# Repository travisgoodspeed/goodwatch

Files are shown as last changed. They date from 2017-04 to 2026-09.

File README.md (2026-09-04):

Howdy y'all,

This is a side project of mine to build a replacement circuit board
for the Casio 3208 module, used in the Casio CA-53W and CA-506
calculator watches.  It is not compatible with the 3228 module used in
the Databank watches, which have four external buttons instead of two.
As a side project, it has no warranty whatsoever and you shouldn't use
it for anything.

In the rare case that you find this project to be useful, you owe me a
pint of good, hoppy pale ale.  All license to use this project is
revoked if you try to pass off a pilsner instead.

In addition to the source code, there is handy documentation in the
[wiki](https://github.com/travisgoodspeed/goodwatch/wiki) and a
general interest website at [goodwatch.org](http://goodwatch.org/).
The wiki's
[DeveloperGuide](https://github.com/travisgoodspeed/goodwatch/wiki/DeveloperGuide)
page might be particularly handy.

73 from Knoxville,

--Travis

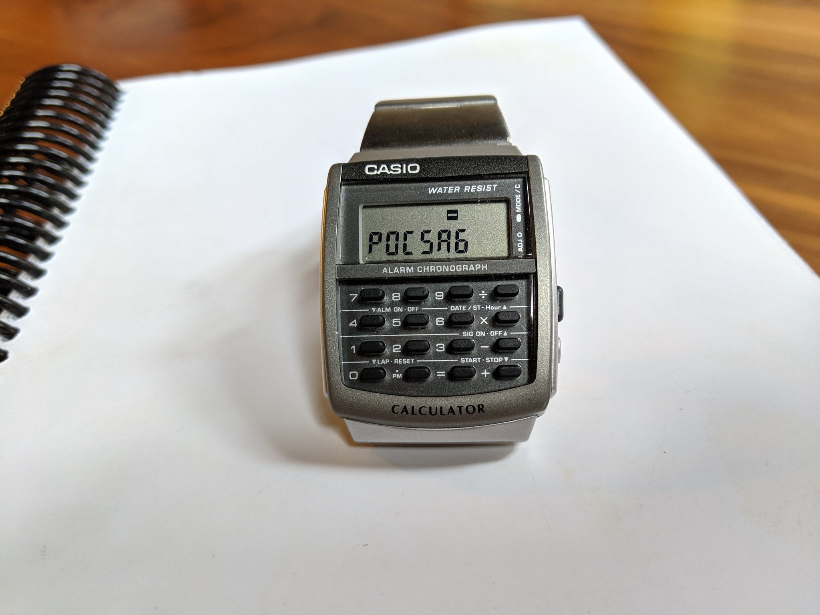
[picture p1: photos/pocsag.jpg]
POCSAG Goodwatch Photo


## Software Status

Our firmware is freely available in this repository, compiling with
the MSP430 GCC compiler packages from Texas Instruments.  It consists
of a
[Clock](https://github.com/travisgoodspeed/goodwatch/wiki/ClockApplet),
a Stopwatch, an RPN Calculator, and a [Hex Memory
Viewer](https://github.com/travisgoodspeed/goodwatch/wiki/HexApplet)
with Disassembler, all written in C.  It compiles in Debian with all
of the MSP430 packages installed.

On watches with a radio, we have
[Morse](https://github.com/travisgoodspeed/goodwatch/wiki/MorseApplet)
and GFSK transmitters, as well as an [OOK
transmitter](https://github.com/travisgoodspeed/goodwatch/wiki/OOK_Example)
that will command cheap remote-controlled relays.  It has a [frequency
counter](https://github.com/travisgoodspeed/goodwatch/wiki/CounterApplet).
The radio is accessible from a host computer over the UART for
building base stations and repeaters, or for rapidly prototyping radio
applications in Python.  P25 and DMR support might come soon.

Additionally, we've written our own client for the CC430's BootStrap
Loader (BSL).  You might find it handy for other projects involving
that chip, or other MSP430F5 and MSP430F6 chips without USB.  You will
need to be a member of the `dialout` group to flash the firmware.

## Hardware Status

Our replacement board is based around the CC430F6147, which combines
an MSP430 microcontroller with an LCD controller and a sub-GHz radio.
Thanks to pin compatibility, our fancy linker scripts produce a
firmware image that works just as well on the older CC430F6137
chip.

The
[GoodWatch30](https://github.com/travisgoodspeed/goodwatch/wiki/GoodWatch30)
is our current hardware revision, with filters that run from 300 MHz
to either 500MHz or 915MHz.  The GoodWatch20 family had narrower
filters at 433MHz, but is still supported.

See `BOM.txt` in the hardware directories for a parts list, and the
wiki for an assembly guide.

## Related Projects

[Pluto](https://github.com/carrotIndustries/pluto) is a replacement
PCB for the Casio F-91W that is also based on an MSP430.  We happily
use that project's [energy
monitor](https://github.com/carrotIndustries/energytrace-util)
utility for measuring our power budget.

[Elektronika-1](https://github.com/BenjaminSoelberg/elektronika-1) is
Benjamin Sølberg's replacement board for the Soviet Электроника-1
watch, based on an MSP430FR2433.

[Sensor Watch](https://github.com/joeycastillo/Sensor-Watch/) is Joey
Castillo's ATSAML22 replacement board for the Casio F-91W.  He adds a
backlight, and a 9-pin flex PCB allows you to add a custom sensor to
the watch, rather than have one built into the board.

[Outatime Pro](https://github.com/evyd13/outatime-pro) from Evelien
Dekkers is a replacement board that matches the same Casio
3208 casings as the GoodWatch, but is based on the Sensor Watch Pro.
It adds backlight, a 9-pin FPC connector for custom sensors or boards,
and a PAM8904 for a louder buzzer without the large inductor.

The [CharlieWatch](https://github.com/osresearch/charliewatch) from
Trammell Hudson is a nice little fork of the GoodWatch that uses a
charlieplexed array of LEDs instead of a Casio watchcase.

[iceSIO](https://github.com/icelord75/icesio) matches the same Casio
3208 casings as the GoodWatch, but uses a PIC16 platform with
accelerometer, compass and environmental sensors.

[FaradayRF](https://faradayrf.com/) is a CC430 radio board intended
for amateur use, with a 500mW amplifier and GPS receiver.  Their radio
chain is far more carefully designed than ours, but in time, we hope
that the two projects will communicate with each other.

[openchronos-ng-elf](https://github.com/BenjaminSoelberg/openchronos-ng-elf)
seems to be the most recently maintained firmware for TI's OpenChronos
devkit, which uses the CC430F6137.  See Adam Laurie's
[ChronIC](http://adamsblog.rfidiot.org/2013/03/you-can-ring-my-bell-adventures-in-sub.html)
project for an early example of sniffing OOK traffic and replaying it
from a watch.

[F91 Kepler](https://gitlab.com/_Pegor/kepler_fw) is an OLED and BTLE
replacement for the Casio F91W module.  It uses a CC2640 and has some
rather good documentation.

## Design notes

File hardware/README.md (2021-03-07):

These directories contain different hardware revisions of the
GoodWatch.  When a revision is manufactured, its files are copied to a
new directory and the old may only be updated for documentation
reasons.

The GoodWatch 22 and earlier were designed in Kicad 4, and might be
awkward to open in newer revisions.  The GoodWatch30 is designed in
Kicad 5.

## GoodWatch 30

This is our current design, featuring a new balun and more generous
filters.  Email Travis for some free PCBs if you'd like to build one.

## GoodWatch 20, 21, 22

These designs are outdated, but still supported by software.  They
have a narrower filter at 433MHz than the GoodWatch30, and sharp corners which must be clipped before assembly.

## GoodWatch 10

This was the first GoodWatch, which lacked a radio and had minor
mechanical misalignments.  You probably don't want this one anymore.

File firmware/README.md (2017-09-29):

Howdy y'all,

The GoodWatch firmware is in this directory.  You will find user-level
applications in the `apps/` subdirectory, while `*.c` in the root
directory contain low-level drivers.

To add your own application, for one of the smaller examples, such as
`stopwatch.c`.  Your app must provide functions for `_init()` (to run
at startup), `_draw()` (to run every quarter-second for rendering),
and `_exit()` which should just return 0 unless you need to intercept
the Mode button, in which case it may return 1 to delay the exit.  Add
these three functions to a line of the `apps[]` structure in
`applist.h`.

In general, we try not to over-abstract the hardware because we don't
intend the design to be portable away from the CC430.  Include
`<msp430.h>` if you need to access the CC430's IO registers or
`"api.h"` for all the standard functions of the GoodWatch firmware.

Cheers,

--Travis

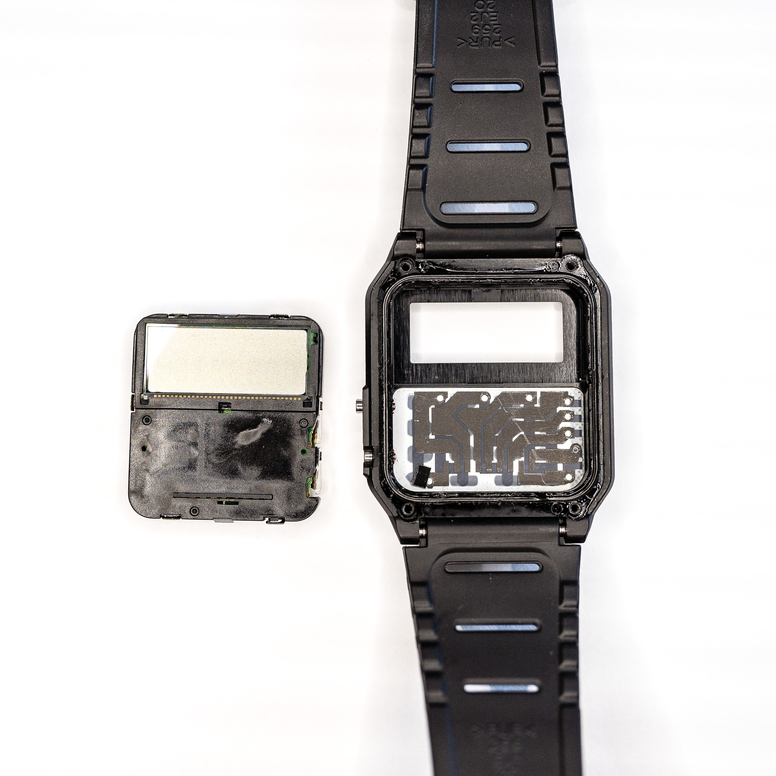
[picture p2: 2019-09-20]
photos/core_module.jpg

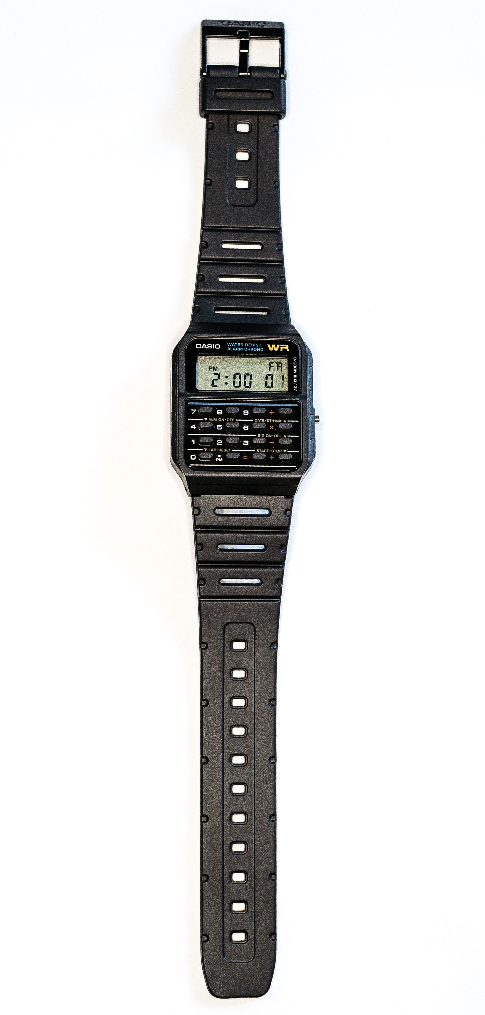
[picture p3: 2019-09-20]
photos/Casio_CA-53W.jpg

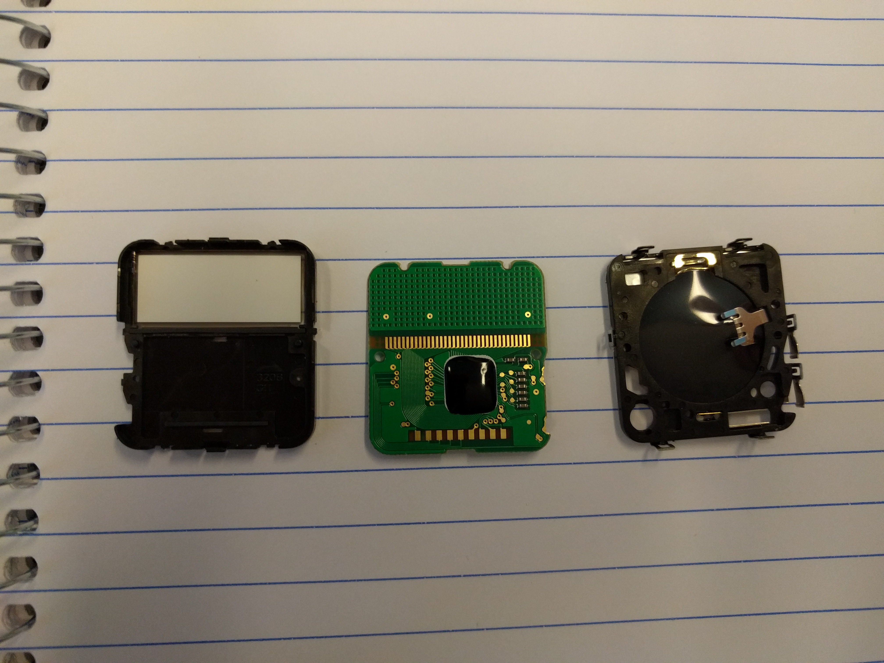
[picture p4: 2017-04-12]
photos/top.jpg

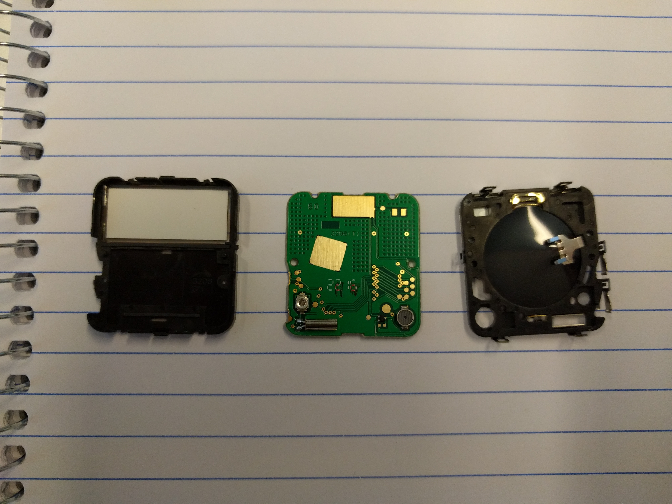
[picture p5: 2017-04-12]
photos/bottom1.jpg

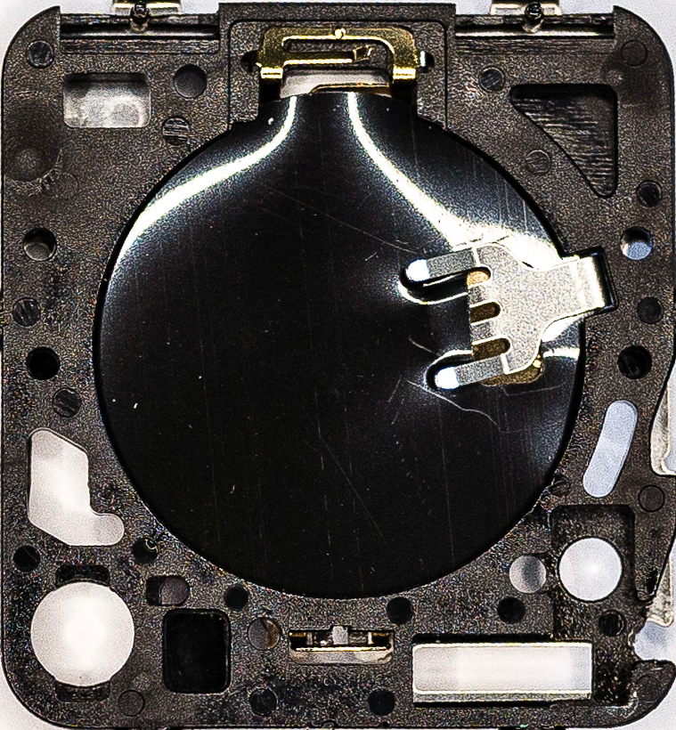
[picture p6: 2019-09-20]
photos/Battery_top.png

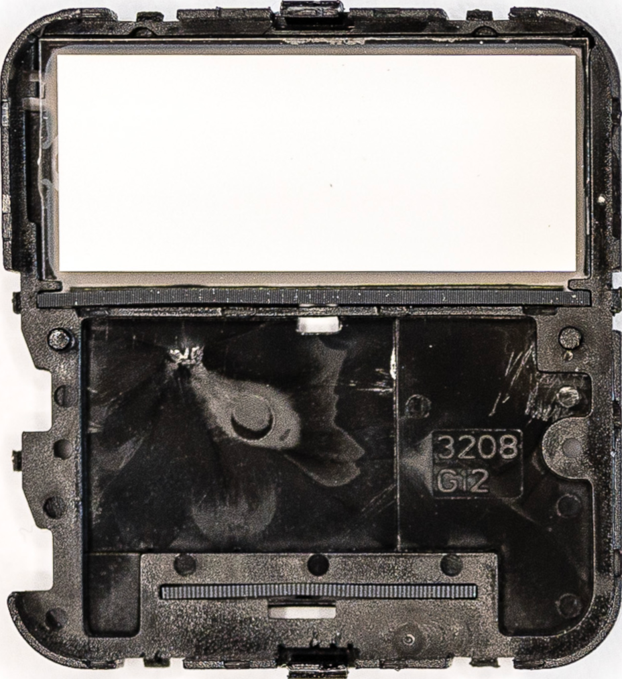
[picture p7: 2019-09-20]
photos/LCD_bot.png

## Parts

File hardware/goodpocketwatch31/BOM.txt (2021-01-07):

Howdy y'all,

This is a textfile BOM for the GoodPocketWatch31. Some substitutions
will be handy, allowing for supplier availability. In general, we use
the same parts as the GoodWatch31, except that the keypad now comes
from tactile switches, and an FTDI chip is available for convenient
USB reprogramming.  You'll probably use a GPW to develop firmware,
while wearing a GoodWatch.

Base parts, required for all watches.

        MfgrPartNo              Digikey             Pkg      Qty   Cmt
U1      CC430F6147IRGCR         296-39985-1-ND      VQFN64   1     CPU
R1      RMCF0402JT75K0          RMCF0402JT75K0CT-ND 0402     1     75K
C1      CL10A476MR8NZNE         1276-6528-1-ND      0603     1     47uF
C2,C3   GRM152C80J104KE19D      490-9997-1-ND       0402     2     0.1uF (<0.3mm thickness)
C4      GRJ155R60J106ME11D      490-13211-1-ND      0402     1     10uF
C5      CL05A474KP5NNNC         1276-1173-1-ND      0402     1     0.47uF
Y1      ABS07-120-32.768KHZ-T   535-11937-1-ND      SMDXTAL  1     32.768kHz6pF

Keypad parts.

B1-17   TL6700AF160QG           EG4385TR-ND                 17     SPST Tactile Switch
BPGM    TL6700NF260QG           EG4386TR-ND                  1     SPST Tactile Switch

Misc Parts

BZ1     PT-1203-3               433-1201-2-ND       THP      1
BT1,2   BE-AAAA-PC-ND           BE-AAAA-PC	    THP	     2     AAAA Battery Holder

Radio parts, only required for the optional SubGHz radio.  Choose one
of the two options for U2, but not the other.

R2      CRGCQ0402F56K           A129648CT-ND        0402     1     56k, 1%
Y2      FA-128 26.0000MF10Z-W5  SER4186CT-ND                 1     26MHz SMD Xtal, 12pF
A1      ANT1204F002R0433A       311-1570-1-ND                1     430MHz Chip Antenna, you probably won't populate this.
J1      0734120110              WM5587CT-ND                  1     u.FL/UMCC coaxial antenna connector, you probably won't populate this.
J3      132289                  ACX1426-ND	    	     1	   Amphenol SMA Connector
C6,C7   CL05C120JB5NNNC         1276-1178-1-ND      0402     2     12pF
C8,C9   GRM152C80J104KE19D      490-9997-1-ND       0402     2     0.1uF (<0.3mm thickness) (Same as C2,C3.)
L1      BLM15HG102SN1D          490-3999-1-ND       0402     1     Ferrite Bead
U2      0500LP15A500            712-1117-1-ND       0805     1     500MHz Low Pass Filter (70cm usage)
U2      0868LP15A020E           712-1585-1-ND       0805     1     868MHz Low Pass Filter (EU unlicensed usage)
U2      0915LP15B02             712-1122-1-ND       0805     1     915MHz Low Pass Filter (33cm usage)
U3      B0310J50100AH           1173-1050-1-ND      0805     1     300MHZ-1GHz Balun
C10     885012205040            732-7535-1-ND       0402     1     220pF DC Bypass Capacitor

USB parts, for on-device reprogramming.

U4      FT232RQ                 768-1008-2-ND                1       USB controller IC
U5      SN74AXC4T774RSVR        296-SN74AXC4T774RSVRTR-ND    1       Voltage Level Translator
J2      DX07S016JA1R1500        670-DX07S016JA1R1500TR-ND    1       USB Type C Receptacle
R3,R4	ERJ-PA2F5101X           P124488TR-ND        0402     2       5.1k, 1%
R5,R6   CR0402-JW-271GLF        CR0402-JW-271GLFTR-ND 0402   2       270 Ohm 5%
D1,D2   VLMS1500-GS08           VLMS1500-GS08TR-ND  0402     2       Red LED
C11-13  GRM152C80J104KE19D      490-9997-1-ND       0402     3       0.1uF (<0.3mm thickness) (Same as C2,C3.)

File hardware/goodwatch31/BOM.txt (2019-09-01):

Howdy y'all,

This is a textfile BOM for the GoodWatch31. Some substitutions will be
handy, allowing for supplier availability. In general, we use the same
parts as the GoodWatch30.

The CC430F6147 is now preferred over the CC430F6137, but the older
chip is still supported by firmware.

Base parts, required for all watches.

        MfgrPartNo              Digikey             Pkg      Qty   Cmt
U1      CC430F6147IRGCR         296-39985-1-ND      VQFN64   1     CPU
R1      RMCF0402JT75K0          RMCF0402JT75K0CT-ND 0402     1     75K
C1      CL10A476MR8NZNE         1276-6528-1-ND      0603     1     47uF
C2,C3   GRM152C80J104KE19D      490-9997-1-ND       0402     2     0.1uF (<0.3mm thickness)
C4      GRJ155R60J106ME11D      490-13211-1-ND      0402     1     10uF
C5      CL05A474KP5NNNC         1276-1173-1-ND      0402     1     0.47uF
Y1      ABS07-120-32.768KHZ-T   535-11937-1-ND      SMDXTAL  1     32.768kHz6pF

Radio parts, only required for the optional SubGHz radio.  Choose one
of the two options for U2, but not the other.

R2      CRGCQ0402F56K           A129648CT-ND        0402     1     56k, 1%
Y2      FA-128 26.0000MF10Z-W5  SER4186CT-ND                 1     26MHz SMD Xtal, 12pF
A1      ANT1204F002R0433A       311-1570-1-ND                1     430MHz Chip Antenna, you probably won't populate this.
J1      0734120110              WM5587CT-ND                  1     u.FL/UMCC coaxial antenna connector, you probably won't populate this.
C6,C7   CL05C120JB5NNNC         1276-1178-1-ND      0402     2     12pF
C8,C9   GRM152C80J104KE19D      490-9997-1-ND       0402     2     0.1uF (<0.3mm thickness) (Same as C2,C3.)
L1      BLM15HG102SN1D          490-3999-1-ND       0402     1     Ferrite Bead
U2      0500LP15A500            712-1117-1-ND       0805     1     500MHz Low Pass Filter (70cm usage)
U2      0868LP15A020E           712-1585-1-ND       0805     1     868MHz Low Pass Filter (EU unlicensed usage)
U2      0915LP15B02             712-1122-1-ND       0805     1     915MHz Low Pass Filter (33cm usage)
U3      B0310J50100AH           1173-1050-1-ND      0805     1     300MHZ-1GHz Balun
C10     885012205040            732-7535-1-ND       0402     1     220pF DC Bypass Capacitor

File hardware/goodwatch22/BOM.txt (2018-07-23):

Howdy y'all,

This is a textfile BOM for the GoodWatch22.  Some substitutions will
be handy, allowing for supplier availability.

Base parts, required for all watches.

        MfgrPartNo              Digikey             Pkg      Qty   Cmt
U1      CC430F6137IRGCR         296-25822-1-ND      VQFN64   1     CPU
R1      RC0201FR-0775KL         YAG2795CT-ND        0201     1     75K
C1      CL10A476MR8NZNE         1276-6528-1-ND      0603     1     47uF
C2,C3   GRM033R61A104ME15D      490-5405-1-ND       0201     2     0.1uF
C4      GRJ155R60J106ME11D      490-13211-1-ND      0402     1     10uF
C5      GRM033R60J474KE90D      490-10409-1-ND      0201     1     0.47uF
Y1      ABS07-120-32.768KHZ-T   535-11937-1-ND      SMDXTAL  1     32.768kHz6pF

Radio parts, only required for the optional SubGHz radio.

R2      RC0201FR-0756KL         YAG2732CT-ND        0201     1     56k, 1%
Y2      FA-128.26.0000MF10Z-W5  SER4186CT-ND                 1     26MHz SMD Xtal, 12pF
A1      ANT1204F002R0433A       311-1570-1-ND                1     430MHz Chip Antenna, you probably won't populate this.
B1      0433BM15A0001E          712-1540-1-ND                1     430MHz Balun/Filter
C6,C7   GRM0335C1E180JA01D      490-9659-1-ND       0201     2     18pF  (19pF are unavailable.)
C8,C9   02016D104KAT2A          478-5266-1-ND       0201     2     0.1uF  (Same as C2,C3.)
L1      BLM15HG102SN1D          490-3999-1-ND       0402     1     Ferrite Bead

For conveniece, there is a readymade BOM on Digikey that includes a
minimum of 10 units of each part with additional quantities on cheaper
parts.  It might be slightly out of date.

http://www.digikey.com/short/q87ncn

A similar BOM from Mouser.

https://www.mouser.com/ProjectManager/ProjectDetail.aspx?AccessID=6053f78fb3

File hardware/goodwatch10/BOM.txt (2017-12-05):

Howdy y'all,

This is a textfile BOM for the GoodWatch10.  Hopefully I'll figure out
one of kicad's fancy BOM management tools before the next hardware
revision.

        MfgrPartNo              Digikey             Pkg      Qty   Cmt
U1      CC430F6137IRGCR         296-25822-1-ND      VQFN64   1     CPU
R1      RC0201FR-0775KL         YAG2795CT-ND        0201     1     75K
C1      CL10A476MQENRBE         1276-6823-1-ND      0603     1     47uF
C2, C3  02016D104KAT2A          478-5266-1-ND       0201     2     0.1uF
C4      GRJ155R60J106ME11D      490-13211-1-ND      0402     1     10uF
C5      GRM033R60J474KE90D      490-10409-1-ND      0201     1     0.47uF
Y1      ABS07-120-32.768KHZ-T   535-11937-1-ND      SMDXTAL  1     32.768kHz6pF

Mouser.de has all the components except for C1, so sourcing an equivalent part:

        MfgrPartNo              Mouser                  Pkg      Qty   Cmt
U1      CC430F6137IRGCR         595-CC430F6137IRGCR     VQFN64   1     CPU
R1      RC0201FR-0775KL         603-RC0201FR-0775KL     0201     1     75K
C1      GRM188R60J476ME5D       81-GRM188R60J476ME5D    0603     1     47uF
C2, C3  02016D104KAT2A          581-02016D104KAT2A      0201     2     0.1uF
C4      GRJ155R60J106ME11D      81-GRJ155R60J106ME1D    0402     1     10uF
C5      GRM033R60J474KE90D      81-GRM33R60J474KE90D    0201     1     0.47uF
Y1      ABS07-120-32.768KHZ-T   815-ABS0712032.768KT    SMDXTAL  1     32.768kHz6pF

In Mouser.fr C1 not available in either of above references, sourcing instead:
C1      81-ZRB18AR60J476ME1L	ZRB18AR60J476ME01L      0603     1     47uF

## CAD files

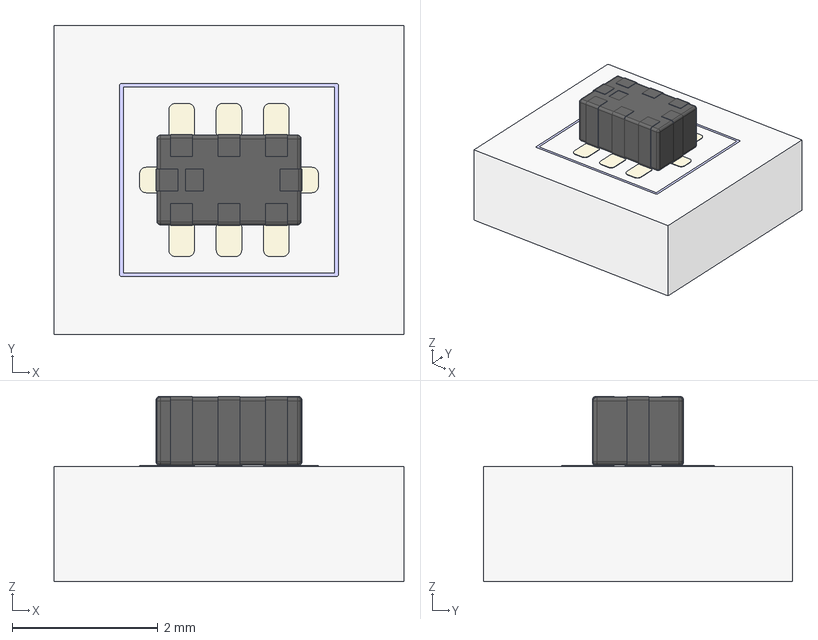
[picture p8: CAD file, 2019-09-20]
hardware/goodpocketwatch31/FreeCad_3D_models/LPF.fcstd
4.80 x 4.24 x 2.54 mm
FCrtYd
FrontSilk
TopPads
Pcb
Filter

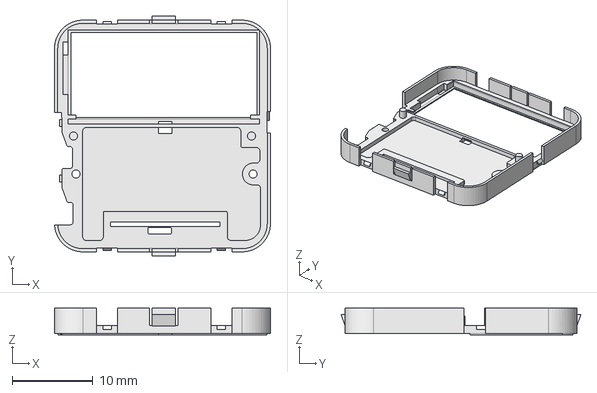
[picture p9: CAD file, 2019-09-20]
measurements/LCD_frame_3D.fcstd
26.7 x 29.6 x 3.30 mm

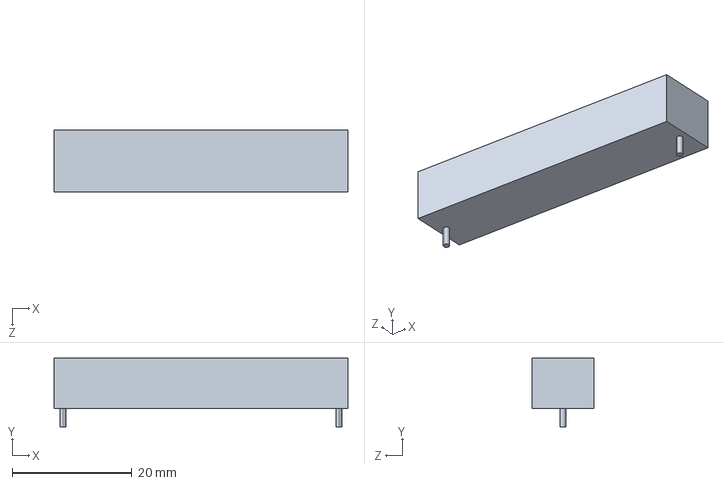
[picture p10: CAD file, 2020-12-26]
hardware/goodpocketwatch31/BE-AAAA-PC.stp
49.0 x 11.4 x 10.4 mm

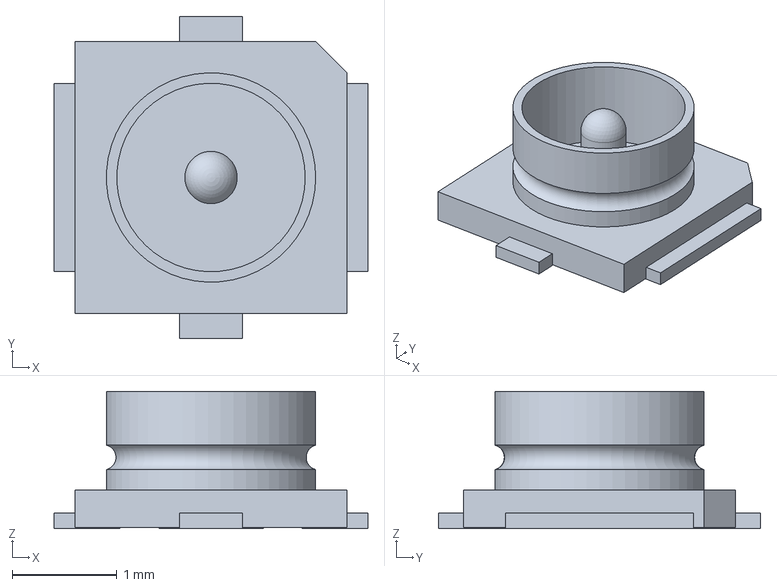
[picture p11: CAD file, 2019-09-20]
hardware/goodpocketwatch31/FreeCad_3D_models/UFL_molex.fcstd
3.00 x 3.08 x 1.31 mm

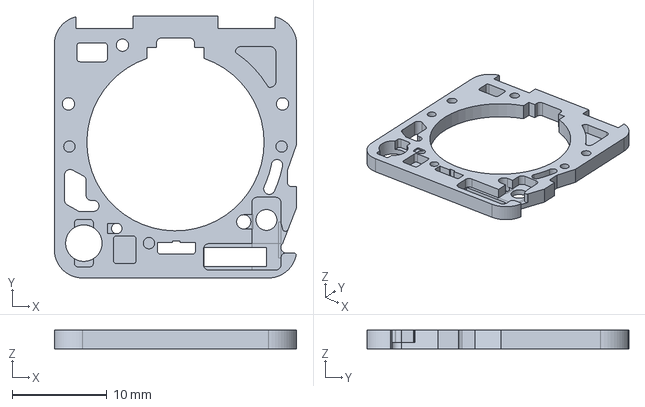
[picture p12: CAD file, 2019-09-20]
measurements/Battery_frame_3D.fcstd
25.6 x 27.7 x 2.00 mm

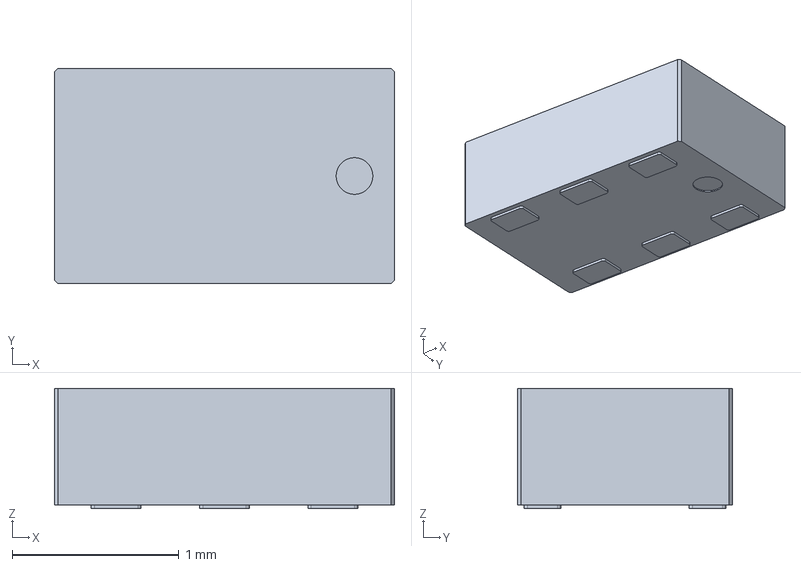
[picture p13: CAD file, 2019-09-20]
hardware/goodpocketwatch31/FreeCad_3D_models/Balun.fcstd
2.04 x 1.29 x 0.72 mm

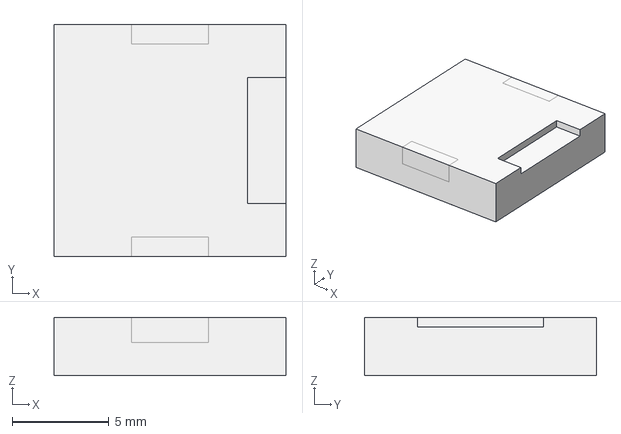
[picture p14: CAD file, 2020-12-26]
hardware/goodpocketwatch31/PT-1203-3.stp
12.0 x 12.0 x 3.00 mm

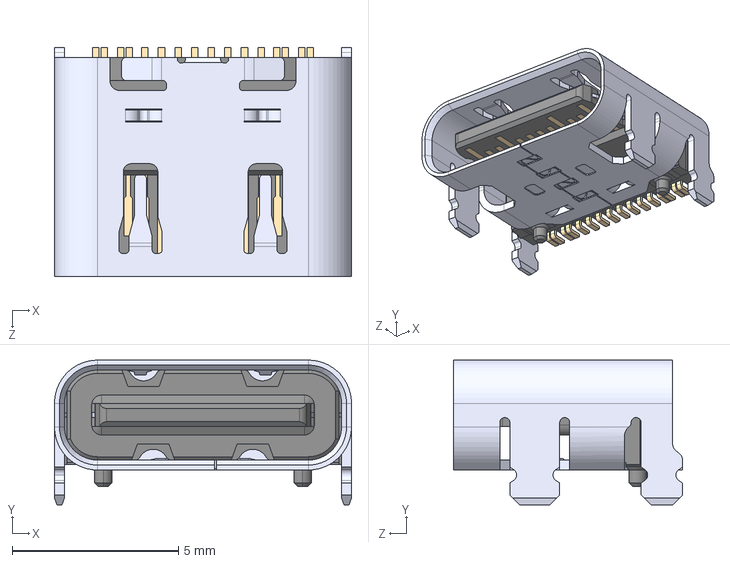
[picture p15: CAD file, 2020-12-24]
hardware/goodpocketwatch31/DX07S016JA1R1500.step
8.94 x 4.36 x 6.90 mm

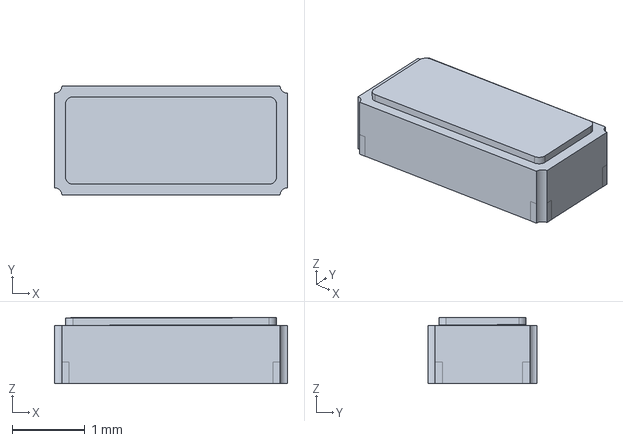
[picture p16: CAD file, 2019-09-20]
hardware/goodpocketwatch31/FreeCad_3D_models/Watch_crystal.fcstd
3.20 x 1.50 x 0.91 mm

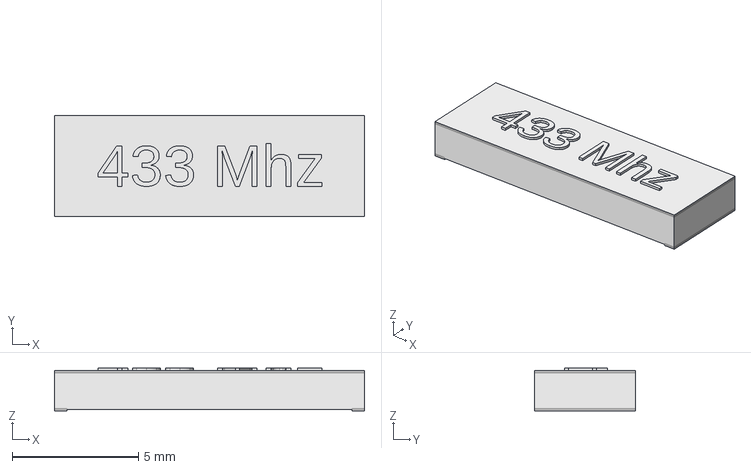
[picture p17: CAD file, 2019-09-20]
hardware/goodpocketwatch31/FreeCad_3D_models/PCB_Antenna.fcstd
12.3 x 4.00 x 1.70 mm

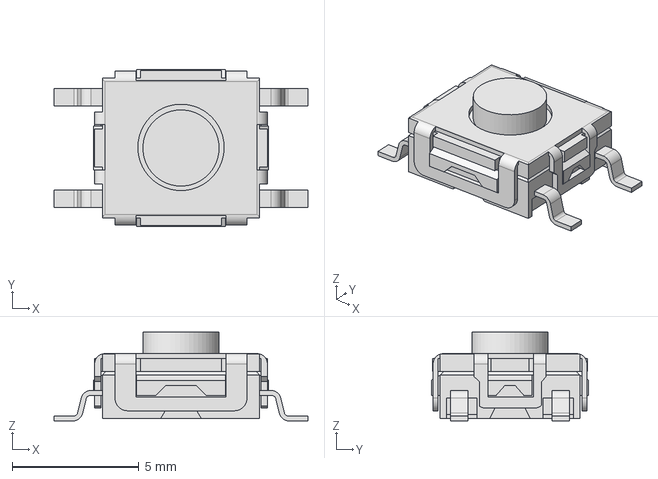
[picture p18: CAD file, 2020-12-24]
hardware/goodpocketwatch31/TL6700.stp
10.00 x 6.20 x 3.50 mm

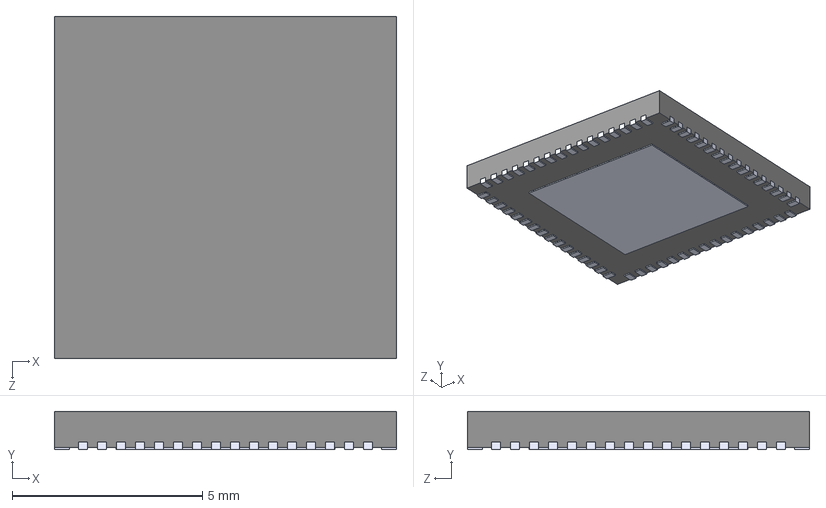
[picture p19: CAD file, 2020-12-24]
hardware/goodpocketwatch31/cc430f6147irgct.step
9.00 x 1.00 x 9.00 mm

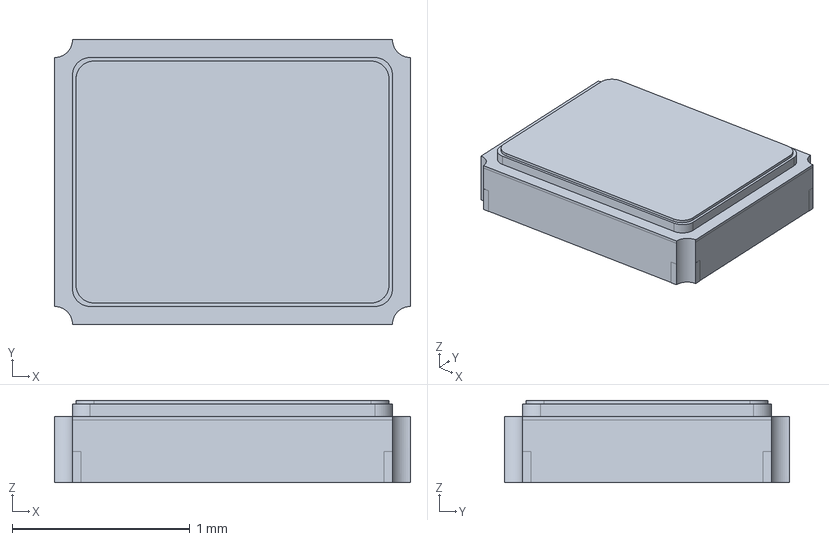
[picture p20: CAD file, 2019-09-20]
hardware/goodpocketwatch31/FreeCad_3D_models/Crystal.fcstd
2.00 x 1.60 x 0.461 mm

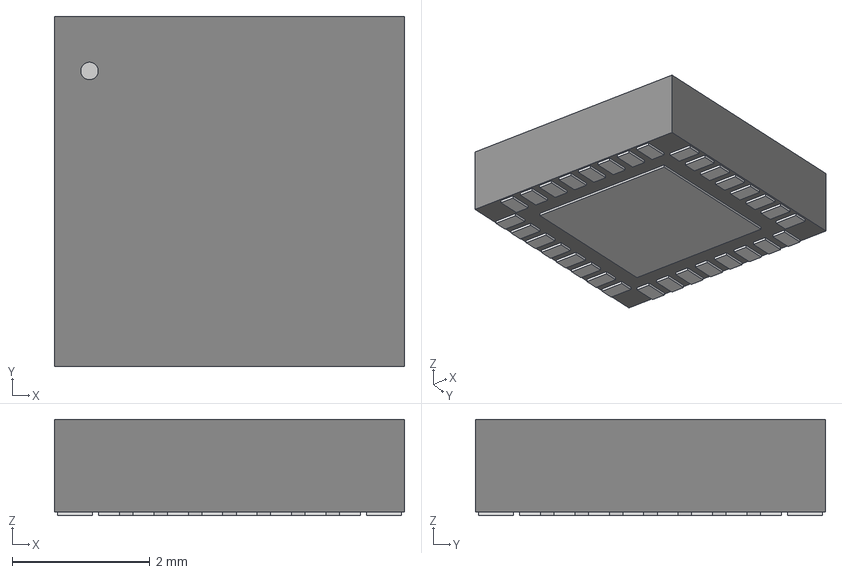
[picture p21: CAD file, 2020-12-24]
hardware/goodpocketwatch31/FT232RQ-REEL_FTD.step
5.08 x 5.08 x 1.40 mm

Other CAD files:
hardware/goodpocketwatch31/sn74axct774rsvr.step
hardware/goodpocketwatch31/132289.stp

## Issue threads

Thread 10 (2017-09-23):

Simulator

travisgoodspeed, 2017-09-23:
Because flashing a wrist-watch takes time, and because minor mistakes in power management can quickly murder our CR2016 battery, we will need an accurate simulator to test the firmware.  We can build this either on [msp430simu](https://github.com/travisgoodspeed/msp430simu/) (Python) or [mspsim](https://github.com/mspsim/mspsim) (Java).

In the short term, a bit of unit testing and maybe an LCD display simulator might be sufficient.  In the long term, we will want accurate models of the clocks and power management, with some mechanism for estimating power drain and comparing the power consumption of separate CPU branches.

Neighbor @cr has volunteered to tackle this issue.

cr, 2018-07-03:
Yeah, probably for the better. I won't get around to contributing anything. Sorry for not being more vocal bout that.

travisgoodspeed, 2018-07-03:
No worries, neighbor.

Closed 2018-07-03.

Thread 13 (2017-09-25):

Programmer Jig

travisgoodspeed, 2017-09-25:
While a watch development kit can be constructed with fly wires and an old GoodFET, it would be far classier to have a programmer jig that could sit beneath a GoodWatch board to program it or remain beneath it for integration testing or to act as a radio host.

Close this issue when we have such a jig, constructed to match the GoodWatch10's layout.  Friction and stiff wires should be used in lieu of pogo plugs, if possible.

brainstorm, 2017-12-20:
Hi Travis, I used this one successfully in the past:

https://github.com/ebuller/openfixture

You just have to mark the pad placements in `Eco1.User` in KiCad, give the `.kicad_pcb` to a openfixture script and the magic of OpenSCAD scripting does the rest (DXF output ready to be laser-cut at your nearest hackerspace).

Handy documentation and assembly guide over here:

http://tinylabs.io/openfixture/

There are more lightweight fixtures out there, but not many parametrized/automated ones and so well suited for KiCad :)

travisgoodspeed, 2020-12-24:
Closing this issue in favor of a pocket watch design that can serve double-duty as a programmer.

sconklin, 2020-12-27:
I am absolutely up for this but . . . I can't commit to any sort of
schedule.

TL:DR is that we were planning to move out of state, but then decided to
stay, but as a consequence almost all my prototyping and fabrication
capabilities are still unavailable.

With any luck, I'll be getting back to normal in a few weeks, but it could
be March before I'm at anything close to full speed.

The openfixture link looks intriguing.

Steve

On Tue, Dec 12, 2017 at 10:26 AM Travis Goodspeed <notifications@github.com>
wrote:

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

travisgoodspeed, 2021-01-03:
No worries, Steve.  Just reopen this issue when you get your lab back together, and your design files for a jig will of course still be accepted to the repo.

Closed 2020-12-24.

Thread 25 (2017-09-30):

Interrupt-Driven getchar()

travisgoodspeed, 2017-09-30:
Currently, the `getchar()` function manually polls the keypad to determine which key is being pressed, and some--but not all--apps will debounce this reading to avoid duplicate presses.  Unfortunately, while rendering the screen at four frames per second looks fine, sampling the keypad only four times per second is a bit annoying.

Close this issue when we use GPIO interrupts to trigger button sampling, so that we can sample away from frame rendering.

Closed 2018-01-27.

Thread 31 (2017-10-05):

Construction and Flashing Guide

travisgoodspeed, 2017-10-05:
We need documentation for how to build a GoodWatch10 board and flash its CC430 with the right firmware.  Close this issue when then documentation is in the wiki.

travisgoodspeed, 2019-10-27:
Closing issue.  The https://github.com/travisgoodspeed/goodwatch/wiki/ConstructionGuide page of the wiki now provides construction details and links to the flashing guides.

Closed 2019-10-27.

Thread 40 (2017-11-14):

300-1000MHz Balun

skytee, 2017-11-14:
Replace Johanson 0433BM15A0001 433MHz balun with Anaren B0310J50100AHF 300-1000MHz balun. Same dimensions, almost same pinout (do not connect pin 5 and 6).

travisgoodspeed, 2017-12-14:
I'll be merging the new balun this week and ordering a new batch of boards for Shmoocon.  Let anyone with filtering advice speak now or forever hold his peace.

mossmann, 2017-12-14:
There are some SAW filters that would be quite nice.  We may be able to find a series of SAW filters that includes a few different useful frequencies with the same footprint.  However, it would be a hard choice between wideband operation and narrowband operation in a specific band.

mossmann, 2017-12-14:
By far the most significant out of band emissions are harmonics of the RF (twice the center frequency, three times, and so on).  The approach I used on YARD Stick One was to install a low pass filter designed for the 900 MHz band.  This effectively filters out all of the harmonics when using the upper half of the tuning range but only filters out some of the harmonics when using the lower half of the tuning range.  I think this is a pretty good compromise that allows wideband operation.  People who need a cleaner signal for a specific frequency in the lower half of the range (e.g. 433 MHz) would have to modify the board to add a different filter.  On YARD Stick One, this is perhaps a better solution than it would be on GoodWatch because it is easy to add an external filter onto the SMA connector, but I think it is worth considering.

mossmann, 2017-12-14:
The Murata series of SAW filters that includes SF2136E (433 MHz) looks like a good option for a footprint that supports various useful parts (315 MHz, 433 MHz, 868 MHz, 902-928 MHz, and more).  (SM3030-6 footprint)

travisgoodspeed, 2018-04-15:
Dusting off this issue for the GoodWatch30.  I think I'll use the same Anaren B0310J50100AHF as @mossmann suggests from the YardStick One as a balun.

For a wideband filter, the 0915LP15B026E (915MHz) and 0500LP15A500E (500MHz) low-pass filters from Johanson have identical layouts, with only a slight different in component height.

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

travisgoodspeed, 2018-08-02:
This is now drafted into the GW30.  Closing issue.

Closed 2018-08-02.

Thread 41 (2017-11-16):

Recovery from Momentary Oscillator Faults

travisgoodspeed, 2017-11-16:
Every now and then, by act of god or mistake of soldering, the low frequency crystal might fail to oscillate.  The watch will automatically switch to the DCO, displaying the division symbol to indicate the fault.  Running POST by holding the 7 button will display an error message to the same effect.

Often, the fault is recoverable, and the watch can be restored without a reboot.  Close this issue when that behavior is implemented, so that the POST will fix an errant XT1 oscillator.

Closed 2018-04-20.

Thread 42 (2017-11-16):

Capacitor supply issues

qdot, 2017-11-16:
The following capacitors used in the 10 and 20 BOMs are both showing out of stock at digikey and mouser:

- CL10A476MQENRBE (Lead time: estimated 6 weeks at digikey)
- 02016D104KAT2A (Lead time: estimated 2 weeks at digikey)

Might want to find some equivalent parts if there's any plans to release this publicly before the end of the year.

mossmann, 2017-12-14:
Is there a reason that the design uses 0201s instead of 0402s?

travisgoodspeed, 2017-12-15:
On the back side, we don't quite have vertical room for 0402s.  On the front side, they should work wherever there is space to adjust the pads.

skytee, 2017-12-22:
It looks like there is sufficient space on the front to put all resistors and capacitors, and make them 0402. What do you think?

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

etbusch, 2018-01-30:
I replaced the following out-of-stock MuRata caps with TDK replacements:

C2, C3, C8, C9: C0603X6S0J104K030BC [Digi-Key](https://www.digikey.com/product-detail/en/tdk-corporation/C0603X6S0J104K030BC/445-8000-1-ND/2792136)

C6, C7: C0603C0G1E180J030BA [Digi-Key](https://www.digikey.com/product-detail/en/tdk-corporation/C0603C0G1E180J030BA/445-4657-1-ND/2050263)

travisgoodspeed, 2018-02-06:
Closed this issue with updated BOM.txt for the GoodWatch21.  I'll look at larger cap sizes for the GW30.

Closed 2018-02-06.

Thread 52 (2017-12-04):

iClicker Application

travisgoodspeed, 2017-12-04:
Use this issue to track a port of @mossmann's iClicker tools from the IMME.  Close when it can receive and transmit.

travisgoodspeed, 2019-05-11:
Closing this issue, as I've lost interest in clickers.

Closed 2019-05-11.

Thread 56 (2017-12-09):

LCD Charge Pump during RX

travisgoodspeed, 2017-12-09:
The LCD charge pump automatically turns off during radio transmission when `LCDBCPCTL&1` to reduce interference and maintain sensitivity.  This causes the display to dim down and eventually disappear during long receive periods.

Close this issue when we have a way to manage this register, keeping the display active where possible.  The solution will likely be different for each protocol, and perhaps its performance impact isn't enough to worry about.

travisgoodspeed, 2018-07-03:
I've not seen this bug on the CC430F6147, so I'm declaring the bug to be an undocumented hardware errata.  Closing as WONTFIX.

Closed 2018-07-03.

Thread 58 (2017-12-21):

Board thickness is undocumented

jaseg, 2017-12-21:
Awesome project! What thickness are the PCBs though? Standard 1.6mm sounds a bit much to me. I think it would make sense to list this in the BOM.

travisgoodspeed, 2017-12-21:
It would.  I'll check my receipts and close this issue when it's documented.

err4nt, 2018-01-01:
Greetings neighbors, I opened up my 3208 and measured the board thickness at 0.5mm. The picture on https://github.com/travisgoodspeed/goodwatch/wiki/GoodWatch10 has them looking very close in thickness.

travisgoodspeed, 2018-01-07:
I manufactured in .024" (~0.61mm), but 0.5mm would fit better if your manufacturer allows it.

Close this issue when the documentation is updated.

etbusch, 2018-01-30:
My boards manufactured in 0.6mm fit snugly in the enclosure of a CA53W-1 watch. Since 0.6mm thickness is the thinnest commonly available from cheap PCB fabs, perhaps it should be the recommended value for this project.

travisgoodspeed, 2018-02-06:
Fixed in 37d6f73 with the GoodWatch21 schematic.

Closed 2018-02-06.

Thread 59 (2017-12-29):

Castellated holes, workaround (low prior., manuf.)

luftek, 2017-12-29:
Hi, thank you for sharing this project.
Castellated holes:
- [x] some PCB manufacturers don't support castellated holes
- [x] usually some $ diff

Needs a simple change in Edge.Cuts
Similarly I did to pluto watch
https://github.com/carrotIndustries/pluto/issues/11

travisgoodspeed, 2018-02-06:
Thank you kindly for the suggestion, but I think I'd rather keep the cuts in the Gerbers the same as the final release.  Gold Phoenix PCB supports the holes without complaint.

Closed 2018-02-06.

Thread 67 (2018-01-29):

RNG Quality Control

travisgoodspeed, 2018-01-29:
A quick check of the `true_rand()` function as a scatterplot of the high and low bytes shows awkward grouping.  I think that we might need to let the clocks drift further, or perhaps whiten the data through the hardware-accelerated AES module.

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

Use this issue to track the RNG tests, and close it when we're convinced that the samples are good.

travisgoodspeed, 2018-01-29:
The plot above can be recreated like so.

```
x270% ./goodwatch.py --randdump samples2.txt
Fetching samples.
x270% gnuplot
Terminal type set to 'qt'
gnuplot> plot 'samples2.txt'
gnuplot>
```

ea, 2018-01-30:
I've run some tests as well. Could it be that "turbo" mode has a significant effect on this?

I've tested the output with `rngtest` from `rng-tools` which implements standard FIPS 140-2 tests and here are my results.

First, testing `true_rand` as it is:
```
rngtest: starting FIPS tests...
rngtest: entropy source drained
rngtest: bits received from input: 265280
rngtest: FIPS 140-2 successes: 0
rngtest: FIPS 140-2 failures: 13
rngtest: FIPS 140-2(2001-10-10) Monobit: 0
rngtest: FIPS 140-2(2001-10-10) Poker: 13
rngtest: FIPS 140-2(2001-10-10) Runs: 13
rngtest: FIPS 140-2(2001-10-10) Long run: 0
rngtest: FIPS 140-2(2001-10-10) Continuous run: 0
rngtest: input channel speed: (min=9.313; avg=17.296; max=18.626)Gibits/s
rngtest: FIPS tests speed: (min=61.133; avg=62.473; max=63.367)Mibits/s
rngtest: Program run time: 4128 microseconds
```

That's not too bad. All blocks are failing "poker" and "runs" tests, while passing others.
If I stop messing with ACLK divider, I get the following:
```
rngtest: starting FIPS tests...
rngtest: entropy source drained
rngtest: bits received from input: 109440
rngtest: FIPS 140-2 successes: 3
rngtest: FIPS 140-2 failures: 2
rngtest: FIPS 140-2(2001-10-10) Monobit: 1
rngtest: FIPS 140-2(2001-10-10) Poker: 0
rngtest: FIPS 140-2(2001-10-10) Runs: 1
rngtest: FIPS 140-2(2001-10-10) Long run: 0
rngtest: FIPS 140-2(2001-10-10) Continuous run: 0
rngtest: input channel speed: (min=9.313; avg=15.522; max=18.626)Gibits/s
rngtest: FIPS tests speed: (min=57.974; avg=58.257; max=58.869)Mibits/s
rngtest: Program run time: 1874 microseconds
```
So, it might look a bit better. If I also don't mess with DCORSEL in each loop the results look even better :
```
rngtest: starting FIPS tests...
rngtest: entropy source drained
rngtest: bits received from input: 654080
rngtest: FIPS 140-2 successes: 26
rngtest: FIPS 140-2 failures: 6
rngtest: FIPS 140-2(2001-10-10) Monobit: 6
rngtest: FIPS 140-2(2001-10-10) Poker: 1
rngtest: FIPS 140-2(2001-10-10) Runs: 1
rngtest: FIPS 140-2(2001-10-10) Long run: 0
rngtest: FIPS 140-2(2001-10-10) Continuous run: 0
rngtest: input channel speed: (min=6.209; avg=14.538; max=18.626)Gibits/s
rngtest: FIPS tests speed: (min=57.450; avg=58.318; max=60.551)Mibits/s
rngtest: Program run time: 10735 microseconds
```
Last run was longest and 26 out of 32 blocks passed. 6 failed monobit tests which would suggest some bias to either ones or zeroes.

In conclusion, it seems like messing with clocks on each loop makes things worse, but even so the RNG seems "good enough" for what it is. Any actual crypto use would definitely need whitening.

ea, 2018-01-30:
Here's a plot without last two lines in the loop:

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

Indeed looks much better.

Just to be clear, SLAA338 give 3 ways of adding randomness:
- selecting majority of 5
- Each time a CCR LSB is shifted, the BCSCTL1 register has the number five added to it. This addition changes the RSEL bits, causing the DCO speed to change relative to the VLO through each loop.
- Each time a CCR LSB is shifted, the two LSBs from the R12 register are XORed into the DIVA bits of the BCSCTL1.

Second two of these correspond to `UCSCTL1 += 5;` and `UCSCTL5 ^= ((seed & 3) << 8)` respectively. It seems like skipping these two steps makes for better results in this particular case.

ea, 2018-01-30:
I found the bug.
`UCSCTL1 += 5;` is incorrect, I misread the docs. The CC430 in question has DCORSEL bits at bit 4-6 of UCSCTL1 , not 0-3.

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

I'll run longer `rngtest` tests and see what we get.

Closed 2018-04-04.

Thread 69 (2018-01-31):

Unable to set RTC

etbusch, 2018-01-31:
Hey Neighbors,

I'm having an issue with the set function of the clock app. I'm not sure if it's related to the chip errata regarding writing to the RTC, the applet software, or an issue with my particular board. However I've verified that the following happens consistently:

- Hitting the Program button doesn't consistently cause the watch to enter set mode, and sometimes freezes the updating of the clock app

- If I can enter set mode, I can cycle through the fields, but setting any of them causes the watch to lock up and eventually reboot.

If any of you could try to reproduce this, I'd appreciate it. I'll be assembling another board this evening to make sure that it isn't an issue with the soldering or assembly, and if it fixes it, I will close this issue. If it is reproduced, I'll try to dive into the errata workaround and see what the issue is.

Thanks!

ea, 2018-01-31:
I've had a similar issue (lock-up when trying to set the clock and occasiona boot stuck on key init) on at least two boards.

Could I suggest you go back a couple of revisions ? This started happening to me after key interrupts change ( in 6ba460e ). Does going back to 3afe3e464971ea126f91f5995d2257d55850745e maybe solve this ?

Maybe the added key interrupt handling code makes some otherwise unnoticeable board or soldering deficency more prominent?

etbusch, 2018-01-31:
I too sometimes get stuck in a loop during the keypad init sequence. I'll hop back to the commit before the interrupt changes to see if it is reproduced.

travisgoodspeed, 2018-01-31:
Looks like I screwed something up with recent patches.  I don't think this is the RTC errata, unless you are using a different compiler.

Hunting the problem down now.

travisgoodspeed, 2018-01-31:
@etbusch Can you reliably enter the programming mode by pressing `+` and `-` at the same time?

travisgoodspeed, 2018-01-31:
It should be a lot better now, but I'll hold off on closing this issue until the debouncing is a little bit better.

etbusch, 2018-02-01:
Thanks for the prompt responses Travis!

The latest master absolutely fixes the bugs I described. The program button is a little touchy still, especially with the small inset button of the CA53W-1, but it's much better, and I can set the watch!

We could improve the bouncing in and out of time set mode just by not using the program button as a toggle, and making the user complete the set process to return to the clock.

````
  /* The SET button will move us into the programming mode. */
  if(sidebutton_set()){
    settingclock=!settingclock;
  }
````

to

```
 /* The SET button will move us into the programming mode. */
  if(sidebutton_set()){
    settingclock=1;
  }
```

travisgoodspeed, 2018-02-01:
I think I'll make the side buttons latching for convenience, rather than require a complete tour of the time and date.

Closing issue.  Will reopen if there are further problems.

Closed 2018-02-01.

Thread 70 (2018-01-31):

Solder mask clearance excessive

esden, 2018-01-31:
Just got the boards and saw a common mistake done using KiCad defaults. Leaving the default 0.2mm solder mask clearance exposes too much of the adjecent copper. That can lead to shorts and other issues with the assembly.

I would change that setting to be the more common 0.05mm.

Closed 2018-02-06.

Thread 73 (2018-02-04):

Weird LCD problem

deephooloovoo, 2018-02-04:
I have soldered together two watches (one with and one without radio) and both have a weird problem with the LCD. Both post fine, but the LCD is blank.

If I set all segments on, then it shows up, however if certain segments are cleared, the whole LCD goes blank. Some segments which do this are bits  0,1, and 2 of lcdm[3].

Minimal code to reproduce, in main():
```...
  lcd_init();
  lcdm[0x03] &= 0xfe;
  while(1);````

deephooloovoo, 2018-02-04:
hmm, I seem to be mistaken, it only seems to happen on one of the boards (something else happens with that one...)  I suspect I have a solder bridge. I will close this tomorrow if that is the case.

deephooloovoo, 2018-02-04:
It was a bridged solder joint between two of the segment pins. Both now fail during oscillator init.

Closed 2018-02-04.

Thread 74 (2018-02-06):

GoodWatch21

travisgoodspeed, 2018-02-06:
The GoodWatch20 is a nice little board, but it has a few issues, such as the solder mask clearance (#70) and the awkward antenna connector.  Filter changes and capacitor size changes will wait for the GoodWatch30 in order to keep the BOM consistent.

Use this issue to track the GoodWatch21 design, and close it when gerbers have been finalized and the first manufacturing run ordered.

- [x] Adjusted solder mask clearance. #70
- [ ] Better antenna connection.
- [x] Labeling
- [x] UART/BSL diagram in the schematic for programming.
- [x] Rendered gerbers/ZIP.
- [x] Wiki documentation.

Closed 2018-04-04.

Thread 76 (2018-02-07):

Measuring Battery Voltage

travisgoodspeed, 2018-02-07:
To avoid glitching out on a low battery, we need to be able to at least roughly measure its voltage through the ADC.

Known thresholds:
- Above 3V, everything seems to be fine.
- At 2.74V, powering the radio triggers a reboot.

Close this issue when a voltmeter is included and in use.

travisgoodspeed, 2018-06-12:
A skeletal battery voltage application is now implemented and functional.  I'll hold off on closing this issue until a low battery warning is displayed in the clock.

travisgoodspeed, 2018-07-03:
The voltage applet has not been merged into the clock.  Press '1' to get the current voltage in millivolts.

I'll close this issue when a few more features are added.
- [ ] Voltage ranges for the buzzer.
- [ ] Voltage ranges for the radio.
- [ ] Low voltage warning in POST.

travisgoodspeed, 2018-07-07:
I have a patch with support for the REF and ADC10 modules.  I'll merge it after verifying that it doesn't break anything in the LCD or radio.

travisgoodspeed, 2018-07-07:
Both chips are now properly supported, accurately measuring voltage while keeping the reference off at other times.

travisgoodspeed, 2018-07-31:
We now reliably measure voltage in both the CC430F6137 and the CC430F6147.  Closing issue.

Closed 2018-07-31.

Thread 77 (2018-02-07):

Buzzer Support

travisgoodspeed, 2018-02-07:
Use this issue to track buzzer support on P2.7.

travisgoodspeed, 2018-02-08:
Looks like driving the piezo directly from an IO pin wasn't such a great idea.  We won't have functional buzzer hardware until the GW21.

etbusch, 2018-02-08:
What's the issue? Not enough drive current?

travisgoodspeed, 2018-02-08:
Too much current, or too much reflected current, I think.  Whenever I set P2.7 both OUT and high, it glitches into a reboot.

The Casio board uses a transistor to drive the piezo, but I'll try a series resistor in the morning to keep the BOM small.  You can still get a bit of noise by flipping 2.7 between IN and OUT with the output low, but it doesn't sound very nice or loud.

travisgoodspeed, 2018-02-08:
If you'd care to repeat my crash, just uncomment the initialization of the `buzz` module in `main.c`.

etbusch, 2018-02-08:
I'll give this a shot over the weekend. I imagine the reason that the piezo on the original board has a drive transistor and the fairly large inductor in parallel is that the oscillation of the piezo has enough of an effect on the power rails that it can glitch the clock and the chip.

I don't have the equipment to measure the inductor on the original board, but I wonder if a SMD equivalent can be sourced.

travisgoodspeed, 2018-02-08:
So this is what the Chronos watch uses, where Q1 is a BC846 NPN transistor, R4 is 47k, and L1 is 32mH (Johanson L-07C12NJV4).  Sorry for the image quality; the Chronos schematics are only included as a blurry JPEG in the app notes.

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

Still hoping that a simple series resistor will suffice, but we'll see how it goes.

etbusch, 2018-02-10:
I just got my test watch's buzzer wired up (the case is not assembled, and the buzzer has short wires running to it), and it seems to be working just fine. Once I have the alarm functionality in a good place I'll program my other watch and see if the buzzer works inside the case, and update this issue accordingly.

travisgoodspeed, 2018-02-10:
Weird, but excellent news.  Perhaps I shorted a wire somewhere?

I'll try to confirm your results before finalizing the GW21 gerbers.

etbusch, 2018-02-10:
I've confirmed the buzzer working on a second watch. It can do most tones, but some end up sounding a bit funky, maybe due to timing.

I'll be sending a pull request of my alarm functionality shortly, with some extra buzzer code included.

travisgoodspeed, 2018-02-17:
I've confirmed a second watch which bootloops around the buzzer initialization when the buzzer spring is attached.  What could we be doing differently, to see such wildly different results?  Have any of the rest of you fine folks replicated either @etbusch's success or my failure?

etbusch, 2018-02-17:
I will be assembling a third watch for a friend tomorrow and will see what that one does.

etbusch, 2018-02-18:
The third watch I've put together has a working buzzer. All three of these are the CA-53W model, maybe the other cases has different buzzer elements?

travisgoodspeed, 2018-02-18:
I've only been using the 506 case lately.  Will try a 53 early next week.

Closed 2018-04-22.

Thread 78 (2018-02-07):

Alarm Support

travisgoodspeed, 2018-02-07:
Use this issue to track support for an alarm clock.  @etbusch already has a branch is the works at https://github.com/etbusch/goodwatch/tree/alarm

etbusch, 2018-02-10:
I've made good progress on the alarm clock functionality.

I could use some guidance on how to handle non-blocking chimes, but I think it is good enough to push as is.

Closed 2018-02-17.

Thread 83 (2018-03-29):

Building/linking firmware fails

teon, 2018-03-29:
I have an error during linking stage when building firmware:

```
10:21:14 teon@x firmware ±|master|→ make
msp430-gcc -mmcu=cc430f6137 -Wall -I. -Os    -c -o rtcasm.o rtcasm.S
echo "#define GITTAG" 0x`git describe --always` >gittag.h
msp430-gcc -mmcu=cc430f6137 -Wall -I. -Os    -c -o main.o main.c
msp430-gcc -mmcu=cc430f6137 -Wall -I. -Os    -c -o lcd.o lcd.c
msp430-gcc -mmcu=cc430f6137 -Wall -I. -Os    -c -o lcdtext.o lcdtext.c
msp430-gcc -mmcu=cc430f6137 -Wall -I. -Os    -c -o rtc.o rtc.c
msp430-gcc -mmcu=cc430f6137 -Wall -I. -Os    -c -o keypad.o keypad.c
msp430-gcc -mmcu=cc430f6137 -Wall -I. -Os    -c -o apps.o apps.c
msp430-gcc -mmcu=cc430f6137 -Wall -I. -Os    -c -o applist.o applist.c
msp430-gcc -mmcu=cc430f6137 -Wall -I. -Os    -c -o sidebutton.o sidebutton.c
msp430-gcc -mmcu=cc430f6137 -Wall -I. -Os    -c -o power.o power.c
msp430-gcc -mmcu=cc430f6137 -Wall -I. -Os    -c -o uart.o uart.c
msp430-gcc -mmcu=cc430f6137 -Wall -I. -Os    -c -o monitor.o monitor.c
msp430-gcc -mmcu=cc430f6137 -Wall -I. -Os    -c -o ucs.o ucs.c
msp430-gcc -mmcu=cc430f6137 -Wall -I. -Os    -c -o buzz.o buzz.c
msp430-gcc -mmcu=cc430f6137 -Wall -I. -Os    -c -o radio.o radio.c
msp430-gcc -mmcu=cc430f6137 -Wall -I. -Os    -c -o packet.o packet.c
msp430-gcc -mmcu=cc430f6137 -Wall -I. -Os    -c -o dmesg.o dmesg.c
msp430-gcc -mmcu=cc430f6137 -Wall -I. -Os    -c -o codeplug.o codeplug.c
msp430-gcc -mmcu=cc430f6137 -Wall -I. -Os    -c -o rng.o rng.c
msp430-gcc -mmcu=cc430f6137 -Wall -I. -Os    -c -o libs/assembler.o libs/assembler.c
msp430-gcc -mmcu=cc430f6137 -Wall -I. -Os    -c -o libs/morse.o libs/morse.c
msp430-gcc -mmcu=cc430f6137 -Wall -I. -Os    -c -o apps/clock.o apps/clock.c
msp430-gcc -mmcu=cc430f6137 -Wall -I. -Os    -c -o apps/alarm.o apps/alarm.c
msp430-gcc -mmcu=cc430f6137 -Wall -I. -Os    -c -o apps/rpn.o apps/rpn.c
msp430-gcc -mmcu=cc430f6137 -Wall -I. -Os    -c -o apps/hex.o apps/hex.c
msp430-gcc -mmcu=cc430f6137 -Wall -I. -Os    -c -o apps/stopwatch.o apps/stopwatch.c
msp430-gcc -mmcu=cc430f6137 -Wall -I. -Os    -c -o apps/phrase.o apps/phrase.c
msp430-gcc -mmcu=cc430f6137 -Wall -I. -Os    -c -o apps/rngapp.o apps/rngapp.c
msp430-gcc -mmcu=cc430f6137 -Wall -I. -Os    -c -o apps/tuner.o apps/tuner.c
msp430-gcc -mmcu=cc430f6137 -Wall -I. -Os    -c -o apps/morse.o apps/morse.c
msp430-gcc -mmcu=cc430f6137 -Wall -I. -Os    -c -o apps/beacon.o apps/beacon.c
msp430-gcc -mmcu=cc430f6137 -Wall -I. -Os    -c -o apps/iclicker.o apps/iclicker.c
msp430-gcc -mmcu=cc430f6137 -Wall -I. -Os    -c -o apps/submenu.o apps/submenu.c
msp430-gcc -mmcu=cc430f6137 -Wall -I. -Os -T msp430.x -o goodwatch rtcasm.o main.o lcd.o lcdtext.o rtc.o  keypad.o apps.o applist.o sidebutton.o power.o uart.o monitor.o ucs.o buzz.o radio.o packet.o dmesg.o codeplug.o rng.o libs/assembler.o libs/morse.o  apps/clock.o apps/alarm.o apps/rpn.o apps/hex.o apps/stopwatch.o apps/phrase.o apps/rngapp.o apps/tuner.o apps/morse.o apps/beacon.o apps/iclicker.o apps/submenu.o
/usr/bin/msp430-ld: goodwatch section `.rodata' will not fit in region `rom'
/usr/bin/msp430-ld: section .vectors loaded at [000000000000ff80,000000000000ffff] overlaps section .rodata loaded at [000000000000d294,000000000001015d]
/usr/bin/msp430-ld: region `rom' overflowed by 510 bytes
/usr/lib/gcc/msp430/4.6.3/mcpu-430x/mmpy-16/libcrt0.a(_copy_data.o): In function `__do_copy_data':
(.init4+0x12): relocation truncated to fit: R_MSP430_16_BYTE against symbol `__data_load_start' defined in *ABS* section in goodwatch
apps/iclicker.o: In function `tune':
iclicker.c:(.text+0x12): relocation truncated to fit: R_MSP430_16_BYTE against `no symbol'
apps/submenu.o: In function `submenu_draw':
submenu.c:(.text+0xe): relocation truncated to fit: R_MSP430_16_BYTE against `no symbol'
apps/submenu.o: In function `submenu_drawselected':
submenu.c:(.text+0x8e): relocation truncated to fit: R_MSP430_16_BYTE against `no symbol'
/usr/lib/gcc/msp430/4.6.3/mcpu-430x/mmpy-16/libgcc.a(_addsub_sf.o): In function `_fpadd_parts':
/tmp/packerbuild-1000/gcc-msp430/gcc-msp430/src/gcc-4.6.3/build/msp430/mcpu-430x/mmpy-16/libgcc/../../../.././gcc/fp-bit.c:623: relocation truncated to fit: R_MSP430_16_BYTE against symbol `__thenan_sf' defined in .rodata section in /usr/lib/gcc/msp430/4.6.3/mcpu-430x/mmpy-16/libgcc.a(_thenan_sf.o)
/usr/lib/gcc/msp430/4.6.3/mcpu-430x/mmpy-16/libgcc.a(_mul_sf.o): In function `_fpmul_parts':
/tmp/packerbuild-1000/gcc-msp430/gcc-msp430/src/gcc-4.6.3/build/msp430/mcpu-430x/mmpy-16/libgcc/../../../.././gcc/fp-bit.c:811: relocation truncated to fit: R_MSP430_16_BYTE against symbol `__thenan_sf' defined in .rodata section in /usr/lib/gcc/msp430/4.6.3/mcpu-430x/mmpy-16/libgcc.a(_thenan_sf.o)
/usr/lib/gcc/msp430/4.6.3/mcpu-430x/mmpy-16/libgcc.a(_thenan_sf.o):(.debug_info+0x13c): relocation truncated to fit: R_MSP430_16_BYTE against symbol `__thenan_sf' defined in .rodata section in /usr/lib/gcc/msp430/4.6.3/mcpu-430x/mmpy-16/libgcc.a(_thenan_sf.o)
/usr/lib/gcc/msp430/4.6.3/mcpu-430x/mmpy-16/libgcc.a(_clzsi2.o): In function `__clzsi2':
/tmp/packerbuild-1000/gcc-msp430/gcc-msp430/src/gcc-4.6.3/libgcc/../gcc/libgcc2.c:709: relocation truncated to fit: R_MSP430_16_BYTE against symbol `__clz_tab' defined in .rodata section in /usr/lib/gcc/msp430/4.6.3/mcpu-430x/mmpy-16/libgcc.a(_clz.o)
/usr/lib/gcc/msp430/4.6.3/mcpu-430x/mmpy-16/libgcc.a(_clz.o):(.debug_info+0x98): relocation truncated to fit: R_MSP430_16_BYTE against symbol `__clz_tab' defined in .rodata section in /usr/lib/gcc/msp430/4.6.3/mcpu-430x/mmpy-16/libgcc.a(_clz.o)
/usr/lib/gcc/msp430/4.6.3/../../../../msp430/lib/mcpu-430x/mmpy-16/libc.a(vuprintf.o): In function `vuprintf':
/tmp/packerbuild-1000/msp430-libc/msp430-libc/src/msp430-libc-20120224/src/./stdlib/vuprintf.c:433: relocation truncated to fit: R_MSP430_16_BYTE against `no symbol'
collect2: ld returned 1 exit status
make: *** [Makefile:26: goodwatch] Error 1
```

I'm using ArchLinux with the following GCC for MSP430:
https://sourceforge.net/projects/mspgcc/

(aur packages: gcc-msp430 msp430mcu msp430-jtag)

Any idea if it's my compilation setup or a bug in source?

ea, 2018-03-29:
Yep, I ran into that myself this morning. With added alarm code and apps it was indeed pushed over ROM capacity. Phrase app is obviously the biggest hog.

Simple temporary solution is to remove the apps you don't want from the makefile and from applist.c.  I'll try to make a makefile configurable easily ...

travisgoodspeed, 2018-03-29:
Closed with the recent merge.

Closed 2018-03-29.

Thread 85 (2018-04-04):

OOK Emulation Example

travisgoodspeed, 2018-04-04:
Use this issue to track development of a quick emulator for these cheap OOK remote controls, including support for the full power table and safety checks to identify packet frame under/overflows.

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

travisgoodspeed, 2018-04-05:
The OOK example is now fully functional.  I'll close this issue after documented it in the Wiki.

travisgoodspeed, 2018-04-06:
Documentation is at https://github.com/travisgoodspeed/goodwatch/wiki/OOK_Example

I'll add a few screenshots, then close this issue.

etbusch, 2018-04-06:
Awesome! I'm excited to dig into this, and to develop new applications once my LimeSDR mini comes in to replace a failed RTL-SDR. Thanks for keeping the momentum moving forward on this project!

Closed 2018-04-07.

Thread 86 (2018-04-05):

Broken Configuration Code

travisgoodspeed, 2018-04-05:
Last week's PR #84 disables all apps except the clock because of a `Makefile` bug that only applies the list to the last item of the build.

```
x270% make clean all
rm -rf *~ */*~ *.hex *.elf *.o */*.o goodwatch gittag.h html latex
msp430-gcc -mmcu=cc430f6137 -Wall -I. -Os     -c -o rtcasm.o rtcasm.S
echo "#define GITTAG" 0x`git describe --always` >gittag.h
msp430-gcc -mmcu=cc430f6137 -Wall -I. -Os     -c -o main.o main.c
msp430-gcc -mmcu=cc430f6137 -Wall -I. -Os     -c -o lcd.o lcd.c
msp430-gcc -mmcu=cc430f6137 -Wall -I. -Os     -c -o lcdtext.o lcdtext.c
msp430-gcc -mmcu=cc430f6137 -Wall -I. -Os     -c -o rtc.o rtc.c
msp430-gcc -mmcu=cc430f6137 -Wall -I. -Os     -c -o keypad.o keypad.c
msp430-gcc -mmcu=cc430f6137 -Wall -I. -Os     -c -o apps.o apps.c
msp430-gcc -mmcu=cc430f6137 -Wall -I. -Os     -c -o applist.o applist.c
msp430-gcc -mmcu=cc430f6137 -Wall -I. -Os     -c -o sidebutton.o sidebutton.c
msp430-gcc -mmcu=cc430f6137 -Wall -I. -Os     -c -o power.o power.c
msp430-gcc -mmcu=cc430f6137 -Wall -I. -Os     -c -o uart.o uart.c
msp430-gcc -mmcu=cc430f6137 -Wall -I. -Os     -c -o monitor.o monitor.c
msp430-gcc -mmcu=cc430f6137 -Wall -I. -Os     -c -o ucs.o ucs.c
msp430-gcc -mmcu=cc430f6137 -Wall -I. -Os     -c -o buzz.o buzz.c
msp430-gcc -mmcu=cc430f6137 -Wall -I. -Os     -c -o radio.o radio.c
msp430-gcc -mmcu=cc430f6137 -Wall -I. -Os     -c -o packet.o packet.c
msp430-gcc -mmcu=cc430f6137 -Wall -I. -Os     -c -o dmesg.o dmesg.c
msp430-gcc -mmcu=cc430f6137 -Wall -I. -Os     -c -o codeplug.o codeplug.c
msp430-gcc -mmcu=cc430f6137 -Wall -I. -Os     -c -o rng.o rng.c
msp430-gcc -mmcu=cc430f6137 -Wall -I. -Os     -c -o libs/assembler.o libs/assembler.c
msp430-gcc -mmcu=cc430f6137 -Wall -I. -Os     -c -o libs/morse.o libs/morse.c
msp430-gcc -mmcu=cc430f6137 -Wall -I. -Os     -c -o apps/clock.o apps/clock.c
msp430-gcc -mmcu=cc430f6137 -Wall -I. -Os     -c -o apps/submenu.o apps/submenu.c
msp430-gcc -mmcu=cc430f6137 -Wall -I. -Os     -c -o apps/alarm.o apps/alarm.c
msp430-gcc -mmcu=cc430f6137 -Wall -I. -Os     -c -o apps/rpn.o apps/rpn.c
msp430-gcc -mmcu=cc430f6137 -Wall -I. -Os     -c -o apps/hex.o apps/hex.c
msp430-gcc -mmcu=cc430f6137 -Wall -I. -Os     -c -o apps/stopwatch.o apps/stopwatch.c
msp430-gcc -mmcu=cc430f6137 -Wall -I. -Os     -c -o apps/rngapp.o apps/rngapp.c
msp430-gcc -mmcu=cc430f6137 -Wall -I. -Os     -c -o apps/tuner.o apps/tuner.c
msp430-gcc -mmcu=cc430f6137 -Wall -I. -Os     -c -o apps/morse.o apps/morse.c
msp430-gcc -mmcu=cc430f6137 -Wall -I. -Os     -c -o apps/beacon.o apps/beacon.c
msp430-gcc -mmcu=cc430f6137 -Wall -I. -Os     -c -o apps/iclicker.o apps/iclicker.c
msp430-gcc -mmcu=cc430f6137 -Wall -I. -Os  -T msp430.x -o goodwatch rtcasm.o main.o lcd.o lcdtext.o rtc.o  keypad.o apps.o applist.o sidebutton.o power.o uart.o monitor.o ucs.o buzz.o radio.o packet.o dmesg.o codeplug.o rng.o libs/assembler.o libs/morse.o  apps/clock.o apps/submenu.o  apps/alarm.o  apps/rpn.o  apps/hex.o  apps/stopwatch.o  apps/rngapp.o  apps/tuner.o apps/morse.o  apps/beacon.o apps/iclicker.o  -DALARM_APP -DRPN_APP -DHEX_APP -DSTOWWATCH_APP -DRNG_APP -DTUNER_APP -DMORSE_APP -DBEACON_APP -DICLICKER_APP
../bin/printsizes.py goodwatch || echo "Please install python-pyelftools."
21254 bytes of .text (64 %)
32 bytes of .data, 504 bytes of .bss, 20 bytes of .noinit (13 %)
msp430-objcopy -O ihex goodwatch goodwatch.hex
x270%
```

Closed 2018-04-05.

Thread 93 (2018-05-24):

Calibration Applet

travisgoodspeed, 2018-05-24:
We need an applet to calibrate the realtime clock through the `RTCCTL2` register.  Use this issue to track development, closing the issue when the following features are implemented:

- [x] On-device control of the trim settings.
- [ ] Persistence of the trim across reboots.
- [ ] Configuration of a decent default setting.

It would also be nice to calibrate the RTC over the serial port, by observing driver across days, but that will wait for another day.

Closed 2018-07-03.

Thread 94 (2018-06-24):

Output dmesg over radio

ea, 2018-06-24:
It would be nice to be able to dump the debug messages over radio, in case something weird happens.

I've started work on this and have an app that does TX-ing. It will likely need more testing and tweaking of packet sizes , and a proper RX side (rtlsdr script even?). Will be on my branch until ready.

Comments?

travisgoodspeed, 2018-06-25:
This would be handy!

Best bet is probably to have the host computer listening at all times, with the device radio dumping dmesg every hour when configured to do so, and also once at startup of the prior boot's dmesg.

ea, 2018-07-16:
I've been playing around with this and it appears that if the battery is anything less than completely new , and dmesg buffer is a bit long, sending packets very quickly one after another causes a reboot itself. The artificial delay in the transmit loop seems to alleviate this a bit and also helps the receiver keep up.

Currently there are two ways to receive the dmesg log. One, through `goodwatch.py` and option `-B` , which might require a bit of timing, but seems to work fairly well for me. And two, through supplied rtlsdr GnuRadio script, which is seems much cleaner, if one has an rtlsdr lying around.

To go with gnuradio route, one first runs `goodwatch_sniff.py` script which will dump bits into `test.bin`. One might need to fiddle with PPM correction and frequency settings in the `goodwatch_sniff.grc` if it doesn't work out of the box (my rtlsdr has a particularly high PPM correction requirement). Then, after the packets are transmitted, running `decode_goodwatch.py` should spit out the dmesg log.

Anybody willing to test this? To make sure it doesn't suffer from the old "works on my machine only" illness...

It would indeed be cool to have it chirp out only new messages every hour, if in "debug" mode of some sort, but I need to figure out how to schedule it first and how to do a tx callback from outside an app :).

travisgoodspeed, 2018-07-16:
I should have time to try it out this week.

travisgoodspeed, 2018-07-21:
@ea You might try updating your fork to master, then transmitting packets of just the battery voltage, to see where it fails.

travisgoodspeed, 2018-11-11:
@ea I merged the beginnings of a dmesg application.  For now, it just scrolls the buffer on the screen, but we can merge radio code into it soon.

ea, 2018-11-11:
Ah, i see where you are going with this. Neat. I was just playing with the gnuradio receiver the other day and made it easier to use. The trouble was in figuring out the exact frequency due to drift in different SDRs. I'll  update my fork and add some code that might be useful.

ea, 2018-11-19:
I have seen pretty large drifts between 3-4 devices i have, but i suspect one to be an outlier due to poor soldering on my side. I don't have a gw30 built yet so i'd stay out of that.

I added a simple gnuradio rtlsdr script that can receive messages as sent by beacon app (and my prototype dmesg sending app) here https://github.com/ea/goodwatch/tree/sdr_testing/bin/sdr

I didn't make a pull request as i'm unsure if you want to taint your repo with sdr stuff, but thought i'd point it out in case somebody ends up needing it.

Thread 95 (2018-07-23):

GoodWatch22 Hardware

travisgoodspeed, 2018-07-23:
The GoodWatch22 has no BOM changes from the '21, but provides for better ground-plane via stitching and other minor changes.  It also moves the antenna connector to the back, to ease routing of the antenna wire in assembly.

Use this issue to track that the design is:
- [x] Drafted
- [x] Gerbers have been finalized.
- [x] Boards have been ordered.

After the GW22, we will widen the filters for the GW30.

etbusch, 2018-07-23:
Does the antenna connector on the back allow for the fitment of the Yageo antenna inside the watch case?

travisgoodspeed, 2018-07-23:
@etbusch Sadly not.  The Casio case doesn't leave enough internal room for the Yageo antenna, unless you provide some external source of power.

etbusch, 2018-07-24:
Gotcha. Have we considered the use of a helical pcb antenna (like the Yageo is) embedded into the board itself? I may take some measurements of the Yageo and see about adapting a similar design for a 0.6mm pcb and a more broadband application.

travisgoodspeed, 2018-07-24:
The 433MHz Yageo is far too thick to fit by cuts in the PCB, but a 900MHz antenna might.  Replacing the battery holder and back of the watch module might also provide sufficient room, but it will still be a tight fit.

If you'd care to help figure this out, let me know to spin up an issue for it.

travisgoodspeed, 2018-07-31:
Gerbers have been finalized and boards are on the way.  Closing this issue.

I'll spin up a new issue for the GW30, which will include a wider radio filter design.

Closed 2018-07-31.

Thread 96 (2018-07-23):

Reduced Drawing in Clock App

travisgoodspeed, 2018-07-23:
Close this issue when the clock uses as few CPU cycles as possible to draw the time, to hopefully increase battery life.

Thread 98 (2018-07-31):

EnergyTrace Records

travisgoodspeed, 2018-07-31:
The fine folks behind the Pluto Watch wrote a nice little EnergyTrace tool for Linux, that would allow us to record the power usage of the GoodWatch while running various applications, to measure and compare their current consumption.  Close this issue when nice tooling exists for running energy traces, as well as documentation of expected current consumption in various situations.

https://github.com/carrotIndustries/energytrace-util

Self assigning.  Hardware has been ordered.

travisgoodspeed, 2018-08-17:
After my order being lost by the my.ti website, it finally arrived today.

travisgoodspeed, 2018-08-29:
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

Minimal tracing of power consumption now works.  The initial commit requires my fork of `energytrace-util` until https://github.com/carrotIndustries/energytrace-util/pull/3 is merged.

travisgoodspeed, 2018-08-29:
Documentation is in the Wiki, and it looks like we get just under two years of battery life on a clean board if you have the self restraint not to use the radio.

https://github.com/travisgoodspeed/goodwatch/wiki/EnergyTrace

```
et 60 > energytrace.txt #This will take a minute.
gnuplot energytrace.gnuplot
gnuplot energytrace-txt.gnuplot

                               GoodWatch Current Consumption           
                                                                       
         1e-05 +-----------------------------------------------------------+
               |           +           +           +           +           |
               |                                 "energytrace.txt" ******* |
         8e-06 |-+                                                       +-|
               |      **********                                           |
               |      *        *                                           |
               |*******        *                         **********       *|
         6e-06 |-+             *                **********        *      +*|
               |               *        *********                 *       *|
               |               **********                         *       *|
         4e-06 |-+                                                *********|
               |                                                           |
               |                                                           |
               |                                                           |
         2e-06 |-+                                                       +-|
               |                                                           |
               |           +           +           +           +           |
             0 +-----------------------------------------------------------+
               20          21          22          23          24          25
                                          Seconds                      
                                                                       
../bin/batterylife.py <energytrace.txt
5.825243 µA average consumption
23.500366 months of CR2016 battery life.
nuc16%
```

Closed 2018-08-29.

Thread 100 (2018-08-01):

GoodWatch30 Hardware

travisgoodspeed, 2018-08-01:
Use this issue to track the design of the GW30, which will include wider filters and substantially different layout in Kicad 5.

- [x] Kicad 5 Migration (#99)
- [x] Anaren B0310J50100AHF Balun (#40)
- [x] Johanson 0915LP15B026E 900MHz Low-Pass FIlter (or 0500LP15A500E for 500MHz) (#40)
- [x] Updated BOM

- [x] Finalized Drafting
- [x] Finalized Gerbers
- [x] First manufacturing run.
- [x] Verification, first constructed watch.

travisgoodspeed, 2018-08-02:
This BOM has been updated, but backordered parts will take twelve weeks for delivery, so I won't be manufacturing PCBs for the next month or so.  That'll give me time to extra-super-double-check footprints and maybe drop the chip antenna for SMA or u.FL.

esden, 2018-08-18:
@travisgoodspeed are you still interested in the u.FL footprint instead of the chip antenna? We have enough space there to even add that footprint under the chip antenna footprint. This way we get all the options.

esden, 2018-09-02:
Ok created a pull request #104 just with the u.fl antenna footprint added. Let me know if you are OK with the placement. I would rather resolve that before I dive into more work that builds upon this commit.

I have more changes I would like to propose:
* we can use smaller via on the board to gain bit more routing space and cleaner copper pattern 0.6/0.4 are larger than the default I usually use. We could go to the still very common 0.5/0.3 via size.
* use 0.2 antipad and 0.2 spoke on the back side ground plane the same way as we have it on the front fill. (did not want to change that in case there is some technical reason for that. The only pad that probably should be connected with wide spokes is the battery terminal.
* round the board corners with 2.5mm radius to match the original board found inside the watch. This will make it easier to put it inside the original plastic molding.
* add 1BitSquared internal part tracking codes as custom flields (for example: `key: cap-cer-0402-1u`) to the schematic symbols to make it easier for me to order parts using my existing BOM ordering and P&P workflow.

Not sure what else but I will communicate it if I run into something else. :) I can have all these changes done by Tuesday depending on when I get the go ahead ;-)

travisgoodspeed, 2018-09-29:
I'm now wearing a GoodWatch30!  Happily closing this issue.

Closed 2018-09-29.

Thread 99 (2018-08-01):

Kicad 5 Migration

travisgoodspeed, 2018-08-01:
The existing GoodWatch models use Kicad 4, but starting with the GoodWatch30, we'll be using Kicad 5.  Close this issue when both the PCB and the schematic are properly loading in Kicad 5.

Closed 2018-08-01.

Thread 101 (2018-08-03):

Shabbat Applet

travisgoodspeed, 2018-08-03:
Close this issue when we have a Shabbat mode that disables the keypad and Mode button, displaying the time while ignoring all user input until the Set button is pressed and released.

Closed 2018-08-03.

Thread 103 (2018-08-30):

Power Improvements

travisgoodspeed, 2018-08-30:
Now that we have power profiling, we ought to use its feedback to reduce the power consumption of the watch's Clock applet.  Close this issue when changes are available and well documented, along with a trace of all that was tried.

--Travis

travisgoodspeed, 2018-08-31:
So first, let's compare usage while disabling some of our older optimization.  We used to always draw the whole time on every frame, 32µA for 4 months of life; today's opportunistic drawing measures 5.8µA, for 23 months of life.  That's one hell of a difference, but it's one that was already committed a few months ago.  Perhaps we could do still better?

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

Currently, we run the clock at 32kHz because current consumption is roughly linear with the CPU's main clock frequency, but now that we are doing as little as possible in each frame, perhaps we are no longer in that linear range?  Sure enough, our 5.8µA of consumption drops to 3.5µA when we idle at 1MHz, completing our frame drawing faster and going back to sleep.  This grows our expected lifetime to 38 months!

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

- [ ] Check this box when the watch runs at high speed at all times.
- [ ] Check this box when Morse and Beep are verified to be compatible with the new core frequency.

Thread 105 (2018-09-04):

CC430F6147 Battery Life

travisgoodspeed, 2018-09-04:
Current consumption in the CC430F6147 is roughly ten times that of the F6137, dragging battery life down from 3 years to 6 months.  Close this issue when the cause is found and the battery life matches.

Closed 2018-09-16.

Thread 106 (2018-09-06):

Creation Time

travisgoodspeed, 2018-09-06:
The creation time is currently written manually by the BSL client.  This works fine when flashing over the BSL, but for SBW flashing, it leaves a time far in the future.  Close this issue when the creation time is properly written by methods.

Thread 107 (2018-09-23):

Long Packet Support

travisgoodspeed, 2018-09-23:
Our packet length is currently restricted to the 64 byte FIFO buffer size.  Close this issue when we can transmit and receive larger packets.

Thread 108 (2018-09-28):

Radio Active in Non-Radio Devices

travisgoodspeed, 2018-09-28:
In a GoodWatch30 prototype with a CC430F6147, the following high
current draw was observed in EnergyTrace.  The prototype has no radio,
but ought to gracefully degrade its consumption rather than draw so
much.

```
                                GoodWatch Current Consumption          
                                                                       
         0.00274 +---------------------------------------------------------+
                 |           +          +           +      A   +           |
         0.00272 |-+                             "energytrace.txt"    A  +-|
                 |                                        A A              |
          0.0027 |-+     A      AA               AA A        A     A AA  +-|
                 |A  AA A A  A      A   A        A  A     A A A  AAA     A |
         0.00268 |A+ AAAA AAAA  AA          A  A AAA   A AAAAA  AA AAAA A+-|
                 |AA AAAAA AA   AAAAAAAAAAA AAA  AAA     AAAAAA  AAAAAA AAA|
         0.00266 |AAAAAA AAAAAAAAAAAA AAAA AAAAAAAAAAAA AAAAAAAAAAAAAAAA AA|
                 |AAAAAAAAAAAAAAAAAAAAAAAAA A  AAAAAAAAAAAAAAAAA AAAAAAAAAA|
                 |AAAAAAAAAAAAAAAAAAAAAAAAAAAAAAAAAAAAAAAAAAAAAAAAAAAAAAAAA|
         0.00264 |AAAAAAAAAAAAAAAAAAAAAAAAAAAAAAAAAAAAAAAAAAAAAAAAAAAAAAAAA|
                 |AAAAAAAAAAAAAAAAAAAAAAAAAAAAAAAAAAAAAAAAAAAAAAAAAAAAAAAAA|
         0.00262 |AAAAAAAAAAAAAAAAAAAAAAAAAAAAAAAAAAAAAAAAAAAAAAAAAAAAAAAAA|
                 |AAAA AAAAAAAAAAAAAAAAAAAAAAAAAAAAAAAAAAAAA AAAAAAAAA AAAA|
          0.0026 |AAA     AA          A       AAA  AA A AA    AAAAA AA AAAA|
                 |           +          +           +         AAA          |
         0.00258 +---------------------------------------------------------+
                 10          20         30          40         50          60
                                           Seconds                     
                                                                       
../bin/batterylife.py <energytrace.txt
2631.487862 µA average consumption
0.052022 months of CR2016 battery life.
```

Disabling the radio module fixed the problem, implying that we
do not properly disable the radio hardware when no high frequency
crystal is present.

```
                                GoodWatch Current Consumption          
                                                                       
        0.0000048 +--------------------------------------------------------+
                  |          +           +          +           +          |
                  |                              "energytrace.txt"    A    |
        0.0000047 |-+                        AA      AA          AA      +-|
                  |                                                        |
                  |                                                        |
        0.0000046 |AAA AA        AAAA    AAA    AA         AAAAAAA AA  AAA-|
                  |                                                        |
                  |  AA  AAAAA        AAAA  AA   AA   AAAA          AAA  AA|
        0.0000045 |-+                                                    +-|
                  |                                                        |
        0.0000044 |-+      AA  AAA   AA       AAA         AA   A      AA +-|
                  |                                                        |
                  |                                                        |
        0.0000043 |AA   AAA  AA AAAAAA AA  AA      AAA   AA  AA   AA   AA+A|
                  |                                                        |
                  |          +           +          +           +          |
        0.0000042 +--------------------------------------------------------+
                  10         20          30         40          50         60
                                           Seconds                     
                                                                       
../bin/batterylife.py <energytrace.txt
4.471645 µA average consumption
30.614092 months of CR2016 battery life.
```

This is caused by improper sequencing in `radio_off()` and `radio_strobe()` exiting early if `!has_radio`.

Closed 2018-09-28.

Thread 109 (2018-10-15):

License?

osresearch, 2018-10-15:
What is the license for the firmware source and Goodwatch schematics?

travisgoodspeed, 2018-11-02:
The project under a beerware license, as found in `README.md`.

> In the rare case that you find this project to be useful, you owe me a pint of good, hoppy pale ale. All license to use this project is revoked if you try to pass off a pilsner instead.

Feel free to reuse whatever parts of the code and hardware you like for your excellent CharlieWatch project, but I will collect that pint the next time we're in the same town.

Closed 2018-11-02.

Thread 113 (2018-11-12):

Left-most decimal point doesn't work

BitBangingBytes, 2018-11-12:
Using setperiod(7,1) does not enable the decimal point, this works for the other 7 decimal points to the right however. I noticed the documentation at the top in lcdtext.c seems to address this although it would appear it is referring to it reversed as it refers to the right-most decimal point not working.

I bring this up because on goodwatch.org the image of the watch with all LCD segments working shows all the decimal points being driven successfully. Currently working on a RPN Calc with floating point support which is how I came across the issue.

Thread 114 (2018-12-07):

"Buffer length error" from active UART

travisgoodspeed, 2018-12-07:
A buffer length error has been observed in a GW30 running recent firmware.  This was caused by sidebutton presses being interpreted as UART bytes, and we can correct it by disabling the UART when in the watch casing.

Close when fixed.  Low priority.

travisgoodspeed, 2019-09-08:
This was fixed some time ago.  Closing issue.

Closed 2019-09-08.

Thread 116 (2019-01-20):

Unlucky Number 7

notpike, 2019-01-20:
Hi,

I'm working on an application for the GoodWatch where it can control the TouchTunes jukebox via it's wireless interface. I know that you can add in symbol rates and signal values into the config file but my overall plan is to add features such as receiving and message encoding so it can do more then 10 commands for one PIN. I've already have a working prototype but there's one small glitch...

The problem I'm having right now is that the #7 key pad dose not want to play well when I define a Switch/Case for it (Line 178 in jukebox.c, Link below). For some odd reason when ever the loop detects it being depressed it only transmits for a brief moment then cuts off.  Now when ever I change that case to, for example '.', it works just fine.

I don't believe this being a hardware issue (with the physical keypad) because when I tested this with two separate watches with the same result. Another reason I don't believe it's a physical defect is that the lcd_string() function is still gets triggered when the radio_getstate() equals 19 when the #7 is depressed. Also I've hard coded in 10 cases including the #7 key into the ook application and it worked just fine, it's just something in my code that's making a gremlin appear.

I'm new to programming in C so I'm not quite sure how to fix this. I can work around this so this isn't braking anything but I was wondering if this a known issue or not. The hardware I'm working on is the GoodWatch22. Any advice or tips would be greatly appreciated.

Thank you!

==JukeBox.c==
https://github.com/notpike/goodwatch/blob/master/firmware/apps/jukebox.c

==My Fork==
https://github.com/notpike/goodwatch

travisgoodspeed, 2019-01-20:
Howdy @notpike!

Thanks for a well written issue!  It made this nice and easy to reproduce.

In `jukebox_packettx()`, you only transmit if `radio_getstate()==1`, but sometimes the state will be 20 because the prior packet hasn't yet finished transmission.  You can fix this by either not checking the radio state in `jukebox_packettx()` or by waiting for it to settle out of transmit mode in the beginning of your function.

```C
while((radio_getstate()&~1)==20)
    ;//Do nothing
```

I've patched a local copy of your fork, and it seems to repair transmissions in both ways.  Have fun with it!

The question remains: why is the `packettx()` callback coming before the end of the packet transmission?  Self assigning this issue to figure that out, and I'll close the ticket only after the mystery is solved.

73 from Knoxville,
--Travis

notpike, 2019-01-20:
Cool! Thank you for your help. :D

Closed 2019-10-27.

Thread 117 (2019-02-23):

Morse Code Time

travisgoodspeed, 2019-02-23:
Lacking a light, it would be handy for the watch to beep its own time in Morse, both for the alarm and when the `+` button is held.

Self assigning.  Close when complete.

travisgoodspeed, 2019-02-23:
Morse is now implemented in Master, both when holding (not just pressing!) the `+` button and for the alarm.  Holding this issue open until the feature is documented.

Closed 2019-10-27.

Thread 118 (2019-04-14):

POCSAG/DAPNET Support

travisgoodspeed, 2019-04-14:
Use this issue to track development of a POCSAG receiver, intended for use on Dapnet at 439.9875 MHz.

Progress:
- [ ] Correct modulation, SYNC.
- [ ] Receiving frames.
- [ ] Decoding frames to recover meaningful text.
- [ ] Standalone applet.
- [ ] Power budget calculations.  (*shudder*)
- [ ] Documentation checked for accuracy in source code and wiki.

travisgoodspeed, 2019-04-15:
Successfully decoding packets with some code that ia far too ugly to commit!  Next free weekend should see proper support in the main branch.

travisgoodspeed, 2019-04-20:
The power situation is pretty dire:  We spend 16mA while actively listening, exhausting the coin cell in only six hours!  As a temporary solution, I'm exiting the pager app when no packets have been seen for three minutes.  Later, we can match the transmitter's timeslot to sleep between packets, hopefully extending usage to more than a day.

travisgoodspeed, 2019-05-04:
This module is still a work in progress, but documentation is up on the wiki.
https://github.com/travisgoodspeed/goodwatch/wiki/POCSAG

As far as power management goes, it looks like we can definitely reduce consumption from 16mA to slightly more than 1mA by keeping the radio in IDLE except when periodically sampling for the 480ms preamble.  This will also fix the LCD fade out problem on CC430F6137-based watches, and depending on the settling time, we might be able to get even better lifetimes by shutting the radio off entirely between preamble-samplings.

travisgoodspeed, 2019-05-11:
Average draw is down the 4mA by polling for the preamble, and that might be made a bit list.  We're up to 24 hours of battery life.

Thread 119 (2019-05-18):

Support for GCC8

travisgoodspeed, 2019-05-18:
Currently, the project builds with msp430-gcc 4.6.3 as distributed by Debian, but it would be nice to also support msp430-elf-gcc-7.3.2 as distributed by Texas Instruments.  Requested by @docprofsky.

- [x] Dialect differences are fixed, so that all modules compile.
- [x] Linking scripts ported, so that a binary links.
- [x] The firmware works!
- [x] Linking technique is documented.
- [x] The firmware size is reasonable.
- [x] ABI is matched in the CC430F6137 RTC errata fix assembly.

And finally,
- [x] Documentation is updated to reference GCC8.
- [x] @travisgoodspeed wears a GCC8 watch for at least a week.
- [x] GCC8 becomes the default.
- [x] GCC4 support is removed.

travisgoodspeed, 2019-05-18:
A few notes on the linking situation:

The CC430F6137 and CC430F6147 are pretty much the same chip from a software perspective, except for a few fixes of errata and the complete replacement of the ADC with a different and incompatible implementation.  Rather than break break compatibility between them or make a compile-time choice between the two, we simply made a custom linker script with symbols for the I/O devices of *both* chips, then detect at runtime which ADC driver we ought to be using.  This served us well enough in GCC 4.6.3, but in GCC 7 the linking scripts have changed, and we must create a new one.

The most actively maintained fork of GCC for the MSP430 seems to be the one maintained by Mitto Systems for Texas Instruments.
http://www.mittosystems.com/ti-msp430-gcc.html

Wmyers559, 2019-05-18:
I was just encountering this problem and was about to post an issue when I saw this. Is there anything that I can do to give you a hand with this?

travisgoodspeed, 2019-05-18:
A pull request that builds on GCC7 without pulling in a dozen floating point and heap functions would be lovely.  It should be enough to just pull in another printf and sprintf implementation, and maybe trace dependencies to figure out what else is pulling in so many standard library routines.

travisgoodspeed, 2019-05-19:
The new compiler's bloat is largely caused by dropping msp430-libc for newlib, and I've been able to make it fit by installing a new `printf()` implementation to avoid newlib's.  I'll push that up to a branch and merge it if and when I can do so cleanly or reduce the rest of the bloat.

travisgoodspeed, 2019-05-25:
Pushed  a forgotten replacement for `stdio.h` that is needed to prevent redefinition warnings.  You should be able to build the GCC7 branch now with `make -f Makefile.gcc7`.

It is still quite a bit larger than with GCC4.  If it doesn't fit, disable some modules at the beginning of the Makefile.

travisgoodspeed, 2019-05-26:
As one additional headache, the calling convention has changed in GCC7.  Now the first parameter and return value are in R12, rather than R15.

http://www.ti.com/lit/an/slaa664/slaa664.pdf

travisgoodspeed, 2019-12-13:
I pushed code to the GCC7 branch which enabled the RTC errata fix in both calling conventions.  Not yet tested on real hardware.

After testing it and optimizing some code, I hope to merge this into the master branch, making GCC8 the new default compiler.

travisgoodspeed, 2019-12-13:
Some sources of bloat in GCC8's build:

- [ ] `malloc()` and `sbrk()`, when we damned well don't need a heap.
- [ ] `srand()` seems to call `malloc()`.  Replace it in `rng.c`.

travisgoodspeed, 2019-12-20:
GCC8 now works with `make -f Makefile.gcc8 clean sbwflash`.  I'll be cutting out GCC4 support after wearing a GCC8 watch a week or two, to make sure there are no pesky edge cases.

Closed 2020-01-23.

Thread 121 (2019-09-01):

GoodWatch31 Hardware

travisgoodspeed, 2019-09-01:
The GoodWatch31 will be in many ways identical to the '30, except for an experimental backlight.  There will be no significant changes from the BOM, and the LEDs themselves will be optional.

travisgoodspeed, 2019-09-01:
Rohm Semiconductor's [SML-P12VTT86R](https://www.digikey.com/product-detail/en/rohm-semiconductor/SML-P12VTT86R/846-1168-1-ND/5011427) device provides an 0402 LED with minimal height.

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

1divf, 2019-09-02:
Hi Travis,
a backlight would be great!
Some time ago I started to work on a backlight and did some measurements.
Maybe a slim side view LED could be placed within the small gap next to the LCD.
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
The gap is only 0.6mm wide and 0.6mm wide side view LED are not that common :/

In addition a thigh fit might cause some stress on the solder joins when pressing a button. So removing a little bit of plastic and a very accurate placement of the LED might help at this point.

I created a 3D model and some svg files for a kicad fabrication layer.
[CA-53W_frame_3D.zip](https://github.com/travisgoodspeed/goodwatch/files/3565075/CA-53W_frame_3D.zip)
[fab_layer.zip](https://github.com/travisgoodspeed/goodwatch/files/3565009/fab_layer.zip)

Maybe these files will help to find the best spot for a tiny LED.

Best,
Ulf

travisgoodspeed, 2019-09-03:
@1divf These CAD files are excellent!  If you wouldn't mind, please send them as a pull request so that they can become a part of the repo?

travisgoodspeed, 2019-10-12:
To better fit the casing, the GW11 will be manufactured in 0.5 mm (0.020") thickness.

freefuel, 2020-08-31:
is there a preferred board house for the boards?

travisgoodspeed, 2020-09-24:
I use [Gold Phoenix PCB](https://www.goldphoenixpcb.com/).  Their website is a bit janky, but they've done good work since the days when you'd email gerbers and send payment by carrier pigeon.

vgnshlvnz, 2025-03-24:
Dear Travis, @travisgoodspeed

I am new to this game and I would like hands on the board. If you have spare GoodWatch30/31 can you send me 1? I will pay for them. No issue.

freefuel, 2025-03-24:
Please tell me how you managed to send this message from Github

Thank you

Justin

On Mon, Mar 24, 2025 at 1:00 AM Vigneshwaran Ravichandran <
***@***.***> wrote:

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

--
"Never attribute to malice that which can be adequately explained by
stupidity." -Robert. J. Hanlon

travisgoodspeed, 2025-03-24:
I have plenty of boards to share.  Just email your shipping address my way.

--Travis

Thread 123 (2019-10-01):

Question about packet_tx()

notpike, 2019-10-01:
Hi!

I'm working on an TouchTunes wireless remote application and I have a question about the packet_tx() function. Looking at the sample code in ook.c packet_tx() is having an uint8_t casted char array piped in but I'm having some difficulty recreating it with a NEC encoder I'm building. The encoder I'm building creates a 16 byte message and returns a char array (returnValue) which is saved to another char array (button_array). I'm not sure if the whole 16byte value is being saved in the array or not and honestly my next move is to create a 3d uin8_t array but I would like to know what I'm doing wrong or know what's a good way to pass values into packet_tx(). :rofl:

My experience with C is limited so any advice would be appreciated. Bellow is what I have done so far and thanks! Hopefully we can control jukeboxes with this watch soon! :smile:

NEC Encoder: encode() : 108
Command Creation: build_button_array() : 208

https://gist.github.com/notpike/c2b0f53e68cd128e804020a4c080b9c0

travisgoodspeed, 2019-10-02:
Howdy @notpike!

It looks like `char *button_array[10];` is supposed to be an array of ten pointers to byte arrays, and that is well enough, except that you are populating the array with pointers to *stack* memory in `build_button_array()`.

```C
// Build Array
void build_button_array(int pin) {
	char returnValue[17];

	encode(returnValue, jukebox_commands[4],pin);  // Skip
	button_array[0] = returnValue;
```

Because this is stack memory, `char returnValue[17]` will have its contents overwritten by other functions, corrupting your packet before it is transmitted.  And when you uncomment the rest of that function, you are overwriting the same bytes with each additional call to `encode()`.

Instead of maintaining an array in RAM for every button, I'd recommend writing a function that returns the encoded packet in a `static` array, regenerating it only if the command or the pin changes.  This should use just twenty-two bytes of RAM, while still returning in an instant if the command and pin are the same as the last time it was called.

```C
// Build Array
uint8_t* build_jukebox_packet(int cmd, int pin) {
	static int lastpin=-1, lastcmd=-1;
	static uint8_t packet[17];  //Must be static so it isn't overwritten.

	//Update the packet only if the pin has changed.
	if(lastpin!=pin or lastcmd!=cmd)
		encode(packet, cmd, pin);  // Skip

	//Return our static packet value.
	return packet;
}
```

From Knoxville,
--Travis

notpike, 2019-10-02:
Thank you!

notpike, 2019-10-03:
Well good news came with mix blessings lol.

The encoder now works grate, how ever even number keys (0,2,4,6,8) begins to transmit however the message gets malformed. Viewing it with a spectrum analyzer it looks like the transmission gets cut short right at the beginning. Below is a fork of the current progress I've made.

Thanks! :smile:

https://github.com/notpike/goodwatch/tree/jukebox

Closed 2019-10-03.

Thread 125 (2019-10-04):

Add photo showing wire antenna installation to wiki

docprofsky, 2019-10-04:
The wiki does not have any photos showing the modification of the CA506 housing to accommodate the wire-wrap wire to connect to the wrist band for use as an antenna.
Close this issue when this is fixed.

travisgoodspeed, 2019-10-05:
Yup, we need a good assembly guide and we desperately need a good description of the antenna offerings.  Close when a wiki page exists to describe using the construction process, including the antenna.

@ea since you took those fancy photos from your last batch, may I assign this issue your way?

ea, 2019-10-05:
Sure, I was just about to build another one , currently have only one with with metal band, though. I'll write up the assembly process and you can tell me what I did wrong :)

ea, 2019-10-06:
I don't know what a proper way of tracking wiki pages would be, but ...
How's this for a construction writeup?
https://github.com/ea/goodwatch/wiki/Construction-Guide
Photos are in my "construction photos" branch.

I  still need to add a bit about different filter choices and antenna options.
What are all the antenna options? I know about:
- wire antenna out the case
- SMD antenna
- ummc connector

Cheers

travisgoodspeed, 2019-10-07:
For the construction guide, let's begin by documenting the wire antenna woven through the rubber watchband and the wire antenna fed into the stainless steel watchband.  The chip antenna and connector can wait for now.

travisgoodspeed, 2019-10-07:
The construction write-up is great!  Please merge it into the master branch of the wiki.

One minor note: I've found that the antenna wire lasts much longer if a small slit is cut into the backplate with a Dremel tool so that the wire isn't crushed when the case is closed.

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

ea, 2019-10-08:
Added a bit about how i have my antenna on the plastic watch as well as your dremel slit example. Photos are now in my wiki's master branch, so you should be able to clone and merge it into yours.

Cheres

travisgoodspeed, 2019-10-08:
Merged @ea's fork to master.

@docprofsky Please review the merged wiki page at https://github.com/travisgoodspeed/goodwatch/wiki/ConstructionGuide and close this ticket if it includes the documentation you were missing.  Feel free to make any necessary changes, or to assign the ticket to @ea or me if something is still missing.

docprofsky, 2019-10-29:
Apologies for the delay on reviewing the directions. It looks quite good and easy to follow. Thank you.

Closed 2019-10-26.

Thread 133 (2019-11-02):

Packet LEN too short for Jukebox

notpike, 2019-11-02:
Hi,

I found a problem in the Jukebox application I wrote where some PIN's (255 is where I discovered this) will make the raw message too large for the uint32_t array 'packet'. This problem causes the message to be cut off at the end due to encoded 1's making the message longer.

I have a working fix that can be pushed at any time and currently building a NEC decoder to make sure there's no other bugs. The old testing method I had in place didn't check to see if the whole message was intact however I hope to fix this soon. :3

notpike, 2019-11-05:
Successfully tested live Jukebox.

Closed 2019-11-05.

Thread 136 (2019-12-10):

Developer's Guide in Wiki

travisgoodspeed, 2019-12-10:
Close this issue when a page of the wiki explains what to do for a good development environment, both hardware and software.

travisgoodspeed, 2019-12-13:
A first draft has been posted to the wiki,
https://github.com/travisgoodspeed/goodwatch/wiki/DeveloperGuide

Some remaining items before closing this issue:
- [ ] Photo of JTAG on an assembled watch.
- [ ] Explanations of memory usage, other C tips.

Closed 2019-12-13.

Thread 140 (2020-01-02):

Hebrew Calendar

travisgoodspeed, 2020-01-02:
As the first watch with a radio transceiver that is arguably kosher for shabbat (#101), it would be nice if the watch could also display dates in the Hebrew calendar.  Because mistakes might easily be left unfound for years, the test case should compare dozens of calendar dates across the next several years with a host-side library.

The RTC will remain in the standard calendar, with conversions performed as necessary to show the date.

Examples:
[ynd](https://github.com/ynd/clisp-branch--ynd-devel/blob/master/src/spvw_calendar.c)
`cal-hebrew.el` from emacs
[Hebrew Calendar](https://en.wikipedia.org/wiki/Hebrew_calendar)

Features:
- [x] App Skeleton
- [x] Display Day of Week (trivial)
- [x] Display Day of Month
- [x] Display Month Name  (Not abbreviated as a number.)
- [ ] Display Leap Month (Adar 1) properly.
- [x] Accurate date conversion from the RTC.
- [ ] Integration with Shabbat applet #101.
- [x] Test suite runs.
- [x] Test suite accurately verifies the applet.
- [ ] Fall Through Mode with the Clock applet. #139

travisgoodspeed, 2020-01-19:
Shavua tov!

I've ported the example from ynd and added test cases.  The test suite also displays the current day, month, year, and day of week for manual verification.

```
% ./libs/hebrew
Gregorian: 2020.01.19, DOW=0
Days since 1900: 43847
Hebrew: 22    Tevet 5780,   Rishon
```

Closed 2020-01-23.

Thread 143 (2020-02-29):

Somfy Shader App Documentation

travisgoodspeed, 2020-02-29:
With the recent merge of #142 by Natan Talon and Guillaume Weghsteen, we now have support for remote controlling Somfy shaders.  While the code is already in the master branch, this issue will track documentation in the wiki.

Close the issue when documentation is in place.

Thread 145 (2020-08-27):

Where to get started?

cintema, 2020-08-27:
Just came  across this project page, and I find it that amazing that I'm just about to buy a nice black casio ca506 (with inverted LCD) on ebay. I recognized that you're even working on DAPNET reception.
However, I couldn't figure out how to get the PCB for the Goodwatch30 (or even better Goodwatch31, for the proposed backlight support).
Will you produce a "mini-series" of PCBs allowing users (like me) to obtain one or two?
Thank you!

travisgoodspeed, 2020-08-27:
GoodWatch31 hasn't been completed yet, I'm afraid.  There's an [open issue](https://github.com/travisgoodspeed/goodwatch/issues/121) to track its development, but it's stalled as I spend my time on other projects.

To get started, read the [Construction Guide](https://github.com/travisgoodspeed/goodwatch/wiki/ConstructionGuide) and send me your shipping address by email.  It is my first name at radiant machines dot com.  I'll toss four PCBs in an envelope and you can solder them at home with parts from the [GoodWatch30 BOM](https://github.com/travisgoodspeed/goodwatch/wiki/GoodWatch30) ordered from Digikey or Mouser.

Closed 2020-08-27.

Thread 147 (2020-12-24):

GoodPocketWatch31

travisgoodspeed, 2020-12-24:
To date, we've been taking a GoodWatch that's designed to be worn on a wrist and fly-wiring it to an FTDI or JTAG board, then praying to half of Olympus that those tiny little wires won't snap.  This was good early on, because it forced the worn watch to be the primary development target, but it is damned inconvenient when a pull request comes in and it's too much trouble to dig out a devkit and test it.

As a solution to that problem, I'm drafting the GoodPocketWatch31, which features a USB C port and FTDI chip for convenient programming.  It re-uses the LCD from a Casio watch, but provides its own keypad.

- [ ] Schematic Complete
- [ ] PCB Layout Complete
- [ ] Gerbers Locked in Stone
- [ ] Manufacturing
- [ ] Successful Assembly

travisgoodspeed, 2020-12-24:
Haven't lain out copper yet, and it's missing some passives, but this is roughly what I'm aiming for.

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

travisgoodspeed, 2020-12-27:
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

This is a decent draft of a board that ought to be function, with an SMA edge connector for RF, USB C and FTDI for programming, and a full set of buttons.  The USB C circuit is isolated by a power gated level converter, so that the board ought to run for years on two AAAA batteries.

I'll be adding some test points and perhaps breaking out the four remaining GPIO pins before sending this off to be fabricated.

freefuel, 2022-08-25:
Travis if your still working on this please humor us Hobby R/c people and break out some of the GPIO to control servos. fwiw a speaker output would also be awesome.

travisgoodspeed, 2022-08-25:
I've been distracted by other things, but I'll leave a 0.1" proto area and some spare GPIO pins if I ever get back to it.

- [ ] Check when done.

freefuel, 2022-08-25:
how low will the radio tune?

freefuel, 2023-04-14:
Any prayer of you finishing this?

travisgoodspeed, 2023-04-19:
Currently missing is a way to mechanically attach the LCD display and its zebra strip.  I think that if those are omitted, I can finish this up pretty quickly.

freefuel, 2023-04-19:
What if it were a carrier board, with the original watch body attached and the back removed and bolted/screwed together? or perhaps a simpler board is used just for the LCD and watch case to retain the LCD.

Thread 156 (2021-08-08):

Contrast Applet

travisgoodspeed, 2021-08-08:
After a field repair at Defcon, my watch's contrast is set a little too high, courtesy of pressure on the zebra connector.  Close this issue when we have either a Contrast applet that can adjust the LCD controller's contrast settings, or a unified Settings applet that also manages the RTC trim.

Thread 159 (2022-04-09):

Can't flash chip by JTAG, because of "tilib: MSP430_OpenDevice: Unknown device (error = 5)"

vertexi, 2022-04-09:
Hi, I'm using an MSP-EXP430F5529LP launchpad to program the watch. but result in `tilib: MSP430_OpenDevice: Unknown device (error = 5)` error.

there is a detailed result:
```
MSPDebug version 0.25 - debugging tool for MSP430 MCUs
Copyright (C) 2009-2017 Daniel Beer <dlbeer@gmail.com>
This is free software; see the source for copying conditions.  There is NO
warranty; not even for MERCHANTABILITY or FITNESS FOR A PARTICULAR PURPOSE.
Chip info database from MSP430.dll v3.15.0.1 Copyright (C) 2013 TI, Inc.

Using new (SLAC460L+) API
MSP430_GetNumberOfUsbIfs
MSP430_GetNameOfUsbIf
Found FET: ttyACM0
MSP430_Initialize: ttyACM0
Firmware version is 31501001
MSP430_VCC: 3000 mV
MSP430_OpenDevice
tilib: MSP430_OpenDevice: Unknown device (error = 5)
tilib: device initialization failed
```

I thought it might be a `libmsp430.so` issue. Can you help me by providing the libmsp430.so file?

travisgoodspeed, 2022-04-09:
I'm using `libmsp430.so` from the [msp430-gcc](https://www.ti.com/tool/MSP430-GCC-OPENSOURCE) distribution.

vertexi, 2022-04-09:
Hi, there. I run the [msp430-gcc](https://www.ti.com/tool/MSP430-GCC-OPENSOURCE) installation. And copy the `msp430-gcc/bin/libmsp430.so` to the `/usr/local/lib/`. Then problem still exists.

msp430-gcc Version: 9.3.1.2 Release date: 22 Jul 2021

And there is result:
```
root@ubuntu:~/ti/msp430-gcc/bin# mspdebug tilib
MSPDebug version 0.25 - debugging tool for MSP430 MCUs
Copyright (C) 2009-2017 Daniel Beer <dlbeer@gmail.com>
This is free software; see the source for copying conditions.  There is NO
warranty; not even for MERCHANTABILITY or FITNESS FOR A PARTICULAR PURPOSE.
Chip info database from MSP430.dll v3.15.0.1 Copyright (C) 2013 TI, Inc.

Using new (SLAC460L+) API
MSP430_GetNumberOfUsbIfs
MSP430_GetNameOfUsbIf
Found FET: ttyACM0
MSP430_Initialize: ttyACM0
Firmware version is 31501001
MSP430_VCC: 3000 mV
MSP430_OpenDevice
tilib: MSP430_OpenDevice: Unknown device (error = 5)
tilib: device initialization failed
```

tahnok, 2022-04-09:
This might be dumb, but this "unknown device (error =5)" is the error I get when I swap SBWTDIO or SBWTCK (or had a poor electric connection to either)

vertexi, 2022-04-16:
Thank you all!! Finally, I can flash MCU and build the watch now.

The issue about the `unknown device (error =5)` error could attribute to the fake MCU. When I get a brand new MCU, everything works like a charm.

Closed 2022-04-16.

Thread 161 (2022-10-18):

Ship's Bell

travisgoodspeed, 2022-10-18:
We currently support reading the time by Morse Code, but another audio code exists for time:  That of maritime ship's bells, of which I learned from [this twitter thread](https://twitter.com/attiegrande/status/1582477632339587073).

Close this issue when we support chimes for these bells, and documentation of the same.
https://en.wikipedia.org/wiki/Ship%27s_bell

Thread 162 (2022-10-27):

[Hardware] Sourcing processors?

CalobHumble, 2022-10-27:
As of right now, the shortest lead time for compatible processors seems to be 6 weeks, from digikey [[link](https://www.digikey.com/en/products/detail/texas-instruments/cc430f6147irgct/3588864)].  This is fine, but I was hoping someone might have an alternative source for processors, like a known cheap commercial product they could be salvaged from?

Also, kudos on a super interesting project! Looking forward to putting together a class on these at my local makerspace!

CalobHumble, 2022-10-27:
@tahnok Ah, I see I could get a sample from them, but the minimum order seems to be 250 outside of a distributor.  I'll go that route, and try to get a sample to get started with, and just wait out re-order with digikey.

Thanks for the quick response!

tahnok, 2022-10-27:
I'm not sure you even need to ask for a sample:

https://www.ti.com/product/CC430F6147/part-details/CC430F6147IRGCR (I think
that's the right part) has a minimum of 1

On Thu, Oct 27, 2022 at 2:26 PM Calob Humble ***@***.***>
wrote:

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

CalobHumble, 2022-10-27:
I'll have to try later, I didn't make it to that screen, just saw the batch sizes on the comparisons.

CalobHumble, 2022-10-27:
Just an update for anyone looking at this thread, the parts listed above ([https://www.ti.com/product/CC430F6147/part-details/CC430F6147IRGCR](https://www.ti.com/product/CC430F6147/part-details/CC430F6147IRGCR)) is also out of stock on the official TI website.

Closed 2022-10-27.

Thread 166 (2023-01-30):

Bugs in various applications

mchesser, 2023-01-30:
I've been working on tools for finding bugs in MSP430 code and had a look at this repo and found a few bugs.

### Possible OOB write when writing to `dmesg_buffer` (`putchar`)

When writing to the `dmesg_buffer` it appears to be possible for the code to write one byte out-of -bounds. i.e., in the code below if `dmesg_index = DMESGLEN - 1` then the code will write to `dmesg_buffer[DMSGLEN]` (`0x2c00`).

https://github.com/travisgoodspeed/goodwatch/blob/60673a72eaed8878cf79b56a9efcb623a1e7d2f4/firmware/dmesg.c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

I'm entirely sure what the MCU will actually do in this case, but since I think there isn't any memory mapped after that point it will generate an S-NMI.

It looks like that the code should be reordered such that the assignment on line 29 should be performed before `dmesg_index` is incremented.

### Default config does not define enough messages for `ook` button array.

The code at:

https://github.com/travisgoodspeed/goodwatch/blob/60673a72eaed8878cf79b56a9efcb623a1e7d2f4/firmware/apps/ook.c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

Transmits a pre-configured OOK packet from `button_array` when one of the numeric keys (0-9) is held. However, there are 10 buttons but only 9 messages a defined in the default configuration https://github.com/travisgoodspeed/goodwatch/blob/60673a72eaed8878cf79b56a9efcb623a1e7d2f4/firmware/configdefault.h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 this causes the code to dereference an invalid pointer when button '9' is pressed.

### BCD lookup for hours in `stopwatch` app is invalid after 60 hours

This one is very minor, but since the `int2bcd` command only supports conversion for the range 0-59, the `stopwatch` app will start displaying garbage digits for hours if it manages to stay running for over 60 hours, because the hour value is computed using `int2bcd` and does not rollover.

https://github.com/travisgoodspeed/goodwatch/blob/60673a72eaed8878cf79b56a9efcb623a1e7d2f4/firmware/apps/stopwatch.c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

## Bugs in UART debugging interface

I assume that the UART interface is intended for debugging only, but I also found a couple of issues in there as well which might be of interest.

### Incorrect handling of zero length messages in `handle_rxbyte`

Messages sent to the UART interface with the length field set to zero are handled incorrectly. In the `MSG` state, after storing the current byte at `uart_buffer[index]` `index` is incrrementd and compared to `length`, however since the store and increment of index occurs before comparing against length for zero length messages the `index == length` condition will never be true:

https://github.com/travisgoodspeed/goodwatch/blob/60673a72eaed8878cf79b56a9efcb623a1e7d2f4/firmware/uart.c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

### `RANDINT` monitor command can request too many values

This one might already be known, but if you request a large number of random numbers to be generated via `RANDINT`, then the stack allocated buffer `rints` overflows the area of memory reserved for the stack and starts overwriting random memory:

https://github.com/travisgoodspeed/goodwatch/blob/60673a72eaed8878cf79b56a9efcb623a1e7d2f4/firmware/monitor.c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

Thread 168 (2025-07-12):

Basic Fab warnings and practical fixes

harrypm, 2025-07-12:
Just lost about 250USD on making 5 `goodwatch 30` boards so yeah....

I fixed this mess [goodwatch30_fixes.zip](https://github.com/user-attachments/files/21192181/goodwatch30_fixes.zip) would make a proper PR but the wiki really needs a 1-2-3 guide fix.

- Warnings for 0.4mm board size (fabs use 1.6mm as standard and this won't be flagged)
- Corrections on battery terminal connections for better fab support
- Corrections on U2 pads they are too wide spaced for normal SMT fab solder pasting to cover vertical pads sometimes.
- RF antenna wrap wire THT hole to vertically thread though plastics.

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

https://github.com/user-attachments/assets/2129233a-3d0f-4bfa-8de7-34b96473998f

https://github.com/user-attachments/assets/5e0f2637-463a-45bf-919d-432b7a8ced3b

yuvadm, 2025-10-04:
@harrypm where did you fab your updated version? can you confirm it's a good build?

harrypm, 2025-10-04:
> @harrypm where did you fab your updated version? can you confirm it's a good build?

@yuvadm honestly I've been busy working on much more expensive projects like the [MISRC](https://github.com/Stefan-Olt/MISRC), this entire adventure was a favour for a friend I'll get around to finishing stuff properly when I throw more money at the situation, right now I need to focus on outher things financially speaking.

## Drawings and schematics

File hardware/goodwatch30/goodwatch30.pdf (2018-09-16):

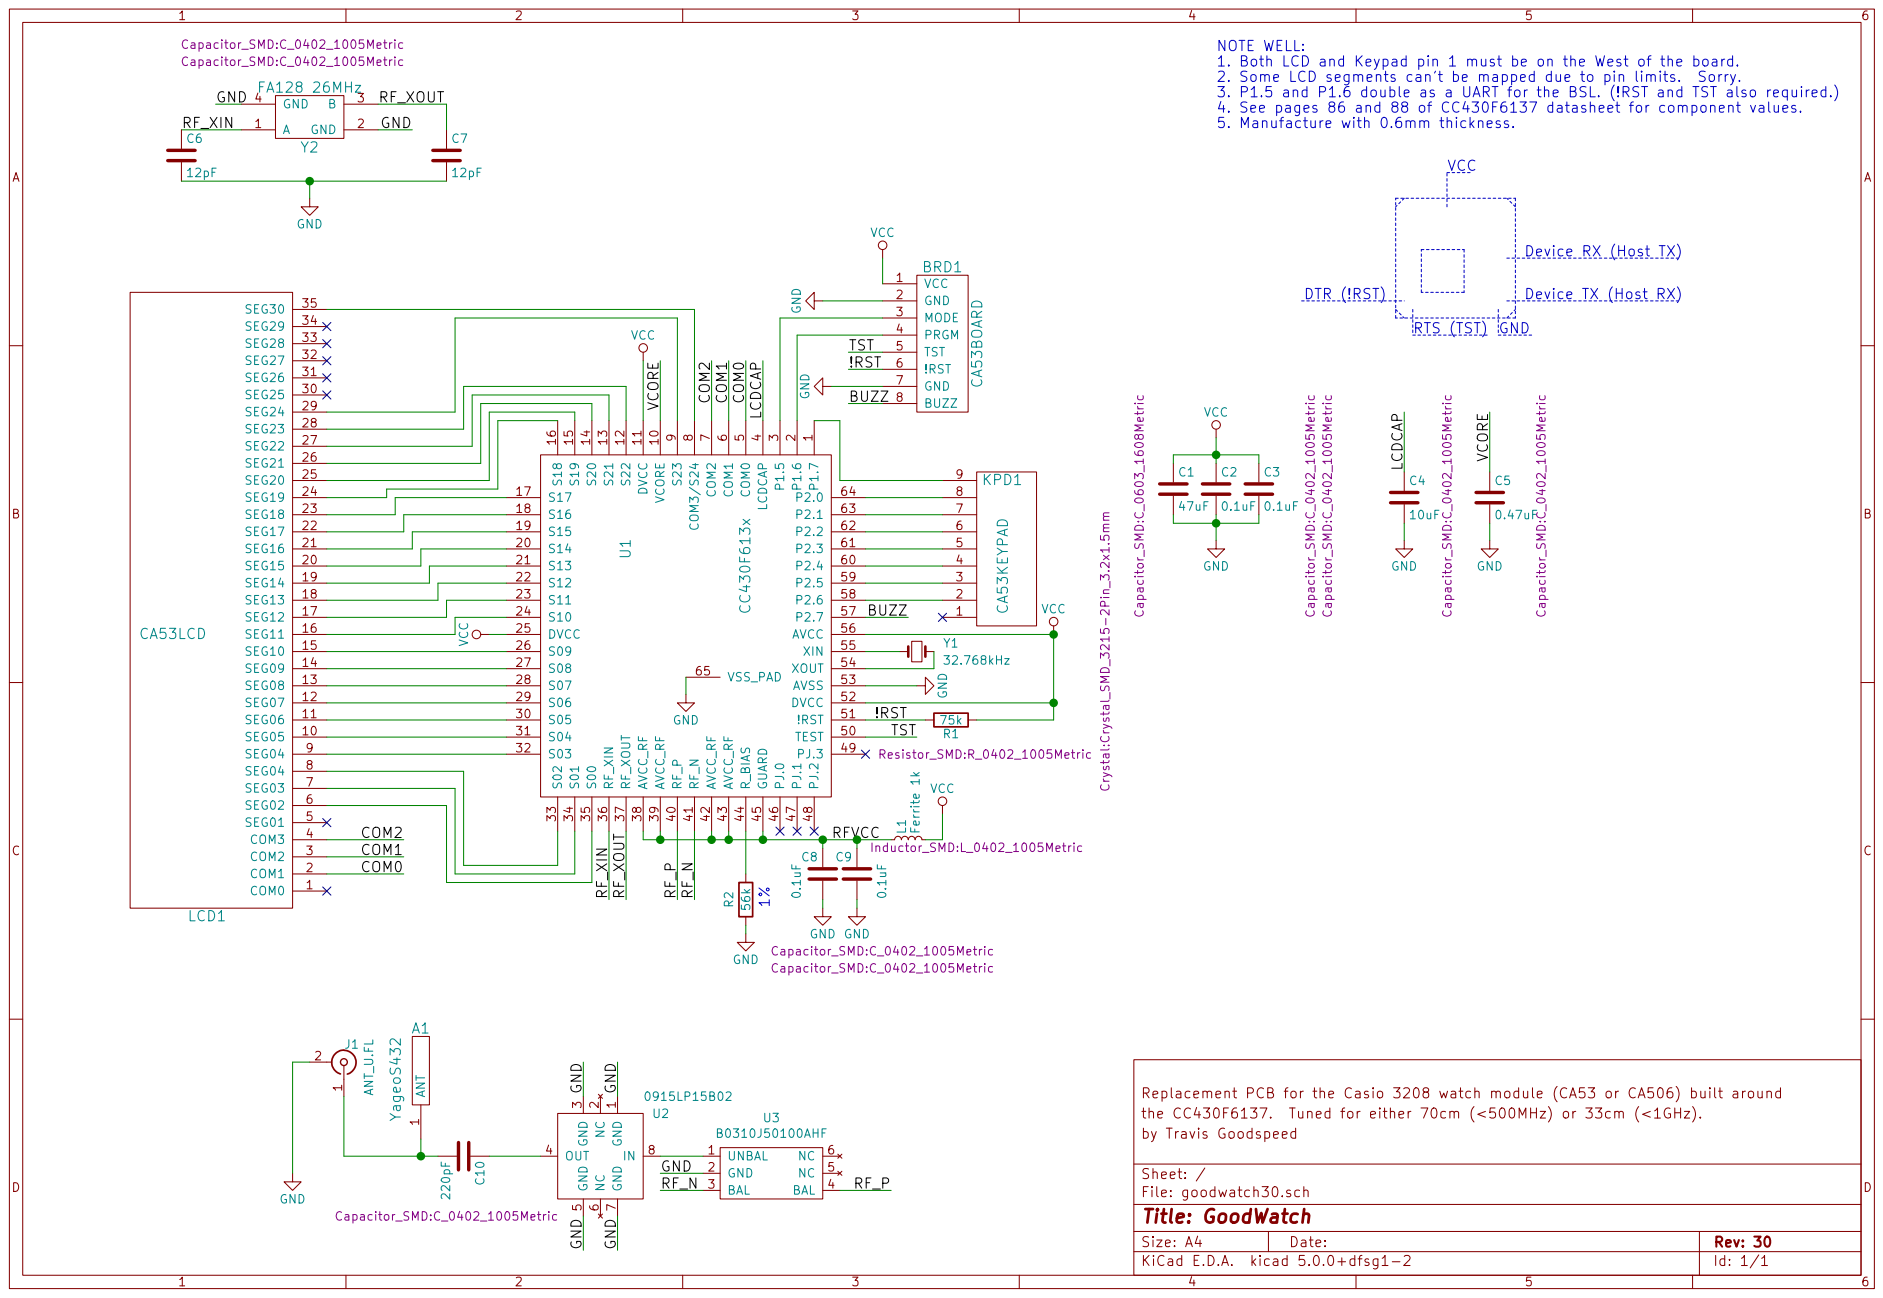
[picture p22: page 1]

NOTE WELL:
1. Both LCD and Keypad pin 1 must be on the West of the board.
2. Some LCD segments can't be mapped due to pin limits. Sorry.
3. P1.5 and P1.6 double as a UART for the BSL. (!RST and TST also required.)

Device RX (Host TX) GND

4 RF_P 40 RF_N 41 AVCC_RF 42 AVCC_RF 43 R_BIAS 44 GUARD 45 PJ.0 46 PJ.1 47 PJ.2 48 PJ.3 49 COM0

!RST
TST

the CC430F6137. Tuned for either 70cm (<500MHz) or 33cm (<1GHz).
File: goodwatch30.sch Sheet: / by Travis Goodspeed

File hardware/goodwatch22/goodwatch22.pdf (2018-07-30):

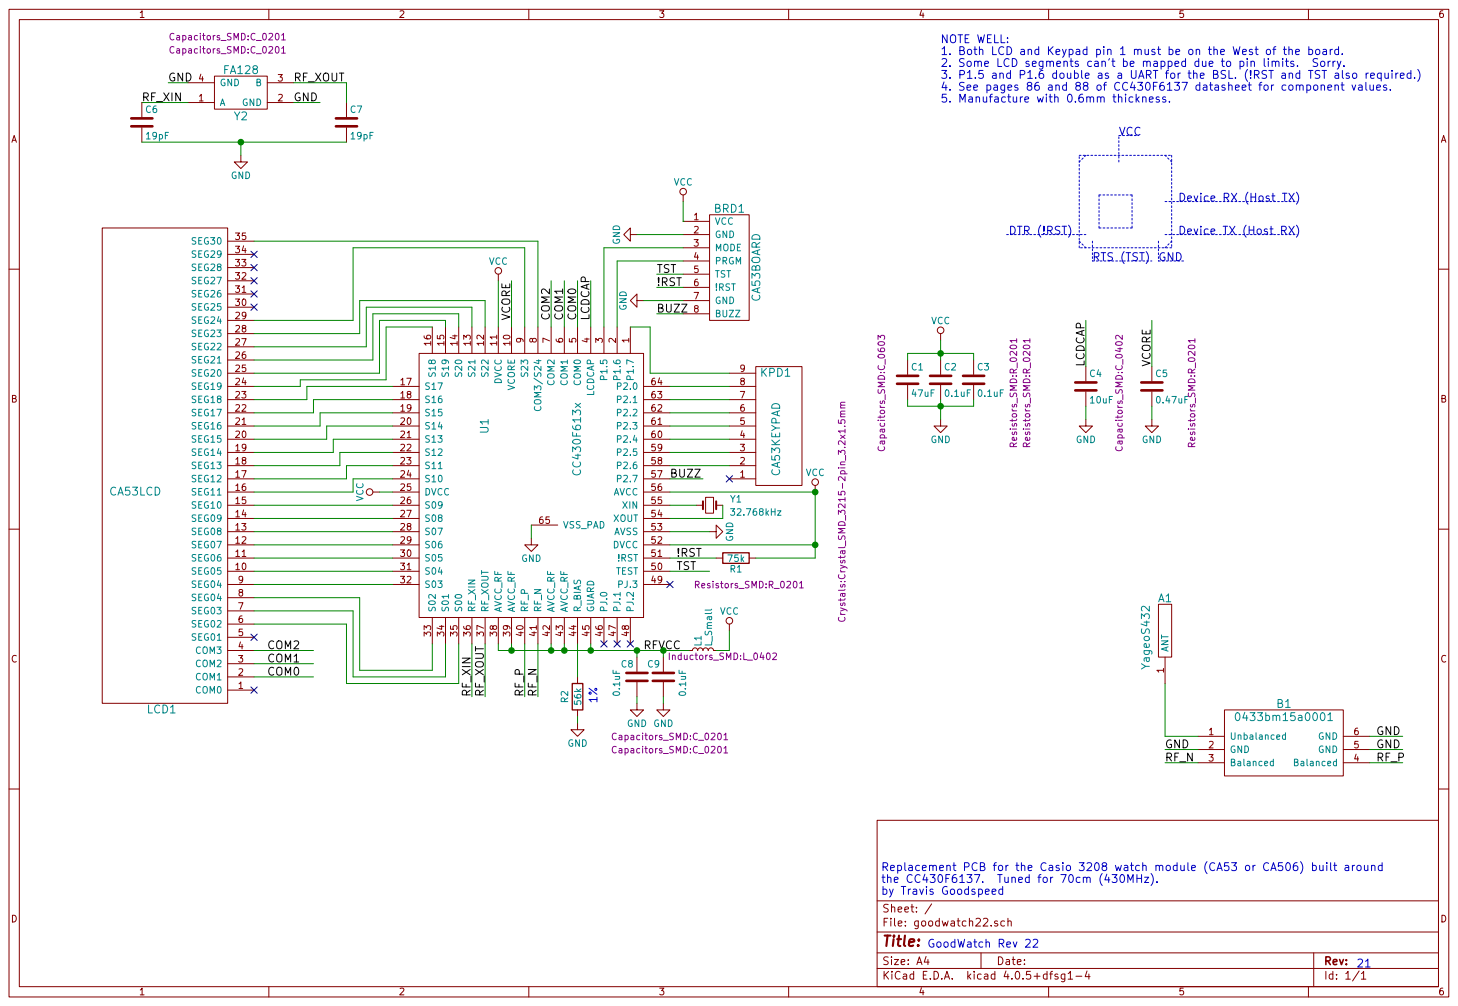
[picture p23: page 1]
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

Device RX (Host TX)

21 Replacement PCB for the Casio 3208 watch module (CA53 or CA506) built around
the CC430F6137. Tuned for 70cm (430MHz).

File: goodwatch22.sch Sheet: / GoodWatch Rev 22
Id: 1/1 Title:

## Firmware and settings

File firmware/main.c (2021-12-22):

/*! \file main.c

  \brief Main module.  This version initializes the LCD and then
   drops to a low power mode, letting the WDT update the display each
   quarter second, or in the handler of a keypress.
*/

#include <msp430.h>
#include <string.h>
#include <stdio.h>
#include <stdlib.h>

#include "api.h"
#include "applist.h"
#include "dmesg.h"
#include "rng.h"

//! Power On Self Test
int post(){
  if(LCDBIV || (LCDBCTL1&LCDNOCAPIFG)){
    /* When the LCD cap is missing, of the wrong value, or
       mis-soldered, the charge pump will be disabled out of
       self-protection.  This looks like a normally dark screen
       abruptly fading to nothing, but you might still be able to
       see the response at the right angle.
    */
    lcd_string("lcd  lcd");
    printf("LCD Error.\n");
  }else if(UCSCTL7&2){
    /* This flag is triggered when the 32kHz crystal has a fault, such
       as if it is not populated or if a little drag of solder reaches
       ground.  Watches with this problem will lose minutes a day, but
       the '430 will fall back to an internal oscillator so that
       non-watch functions still work.
     */
    lcd_string(" crystal");
    printf("32kHz crystal error.");
  /*Can't run this test because of an unfixed errata.
  }else if(has_radio && RF1AIFERR & 1){
    lcd_string("RF  LOWV");
  */
  }else if(has_radio && RF1AIFERR & 2){
    lcd_string("RF OPERR");
  }else if(has_radio && RF1AIFERR & 4){
    lcd_string("RFOUTERR");
  }else if(has_radio && RF1AIFERR & 8){
    lcd_string("RF OVERW");
  }else{
    /* Return zero if everything is hunky dory.
     */
    lcd_string("all good");
    return 0;
  }

  printf("POST failure.\n");
  //We had a failure, indicated above.
  return 1;
}

//! Main method.
int main(void) {
  WDTCTL = WDTPW + WDTHOLD; // Stop WDT

  //Initialize the printf library.
  init_printf(NULL, dmesg_putc);

  //Initialize the various modules.
  dmesg_init();

  printf("RNG ");
  srand(true_rand()); // we do this as early as possible, because it messes with clocks

  printf("REF ");
  ref_init();

  printf("LCD ");
  lcd_init();
  
  lcd_zero();
  printf("rtc ");
  lcd_string("RTC INIT");
  rtc_init();

  lcd_zero();
  printf("osc ");
  lcd_string("OSC INIT");
  ucs_init();
  
  //Recognize the CPU model.
  //descriptor_dump();
  

  lcd_zero();
  printf("buzz ");
  lcd_string("BUZZINIT");
  buzz_init();
  /* Startup tones kill the watch in low battery.
  tone(NOTE_C7, 500);
  tone(NOTE_E7, 500);
  tone(NOTE_G7, 500);
  tone(NOTE_A8, 500);
  tone(NOTE_C8, 500);
  */


  lcd_zero();
  printf("cp ");
  lcd_string("CP  INIT");
  codeplug_init();
  
  lcd_zero();
  printf("rad ");
  lcd_string("RAD INIT");
  radio_init();

  printf("Beginning POST.\n");
  lcd_string("POSTPOST");
  // Run the POST until it passes.
  while(post());

  //Finally we initialize the application.
  lcd_zero();
  lcd_string("APP INIT");
  app_init();
  
  //Keys and buttons are initialized *after* the application.
  printf("key ");
  key_init();
  printf("but ");
  sidebutton_init();
  
  //Unused IO pins must be outputs.
  PJDIR |=  0xF;
  PJOUT &= ~0xF;

  //UART must come after the sidebuttons.
  uart_init();
  
  // Setup and enable WDT 250ms, ACLK, interval timer
  WDTCTL = WDT_ADLY_250;
  SFRIE1 |= WDTIE;


  //'make sbwrftest' will flash an image that beacons repeatedly in
  //Morse, to test the RF chain.
#ifdef RFTEST
  lcd_string("RFTEST");
  radio_on();
  radio_writesettings(0);
  radio_writepower(0x25);
  //codeplug_setfreq();
  radio_setfreq(433920000);
  radio_strobe(RF_SCAL);
  while(1)
    radio_morse("      GOODWATCH  RFTEST " CALLSIGN " " CALLSIGN);
#endif
  

  printf("Booted.\n");
  __bis_SR_register(LPM3_bits + GIE);        // Enter LPM3
  while(1){
    /* These dots oughtn't appear in dmesg, because the main thread
       ought to be paused with all processing in interrupts.  If this
       code executes, we've got a power management problem.
     */
    printf(".");
  }
}

//! Watchdog Timer interrupt service routine, calls back to handler functions.
void __attribute__ ((interrupt(WDT_VECTOR))) watchdog_timer (void) {
  static int latch=0;
  static int oldsec;

  /* When the UART is in use, we don't want to hog interrupt time, so
     we will silently return.
  */
  if(uartactive)
    return;

  if(sidebutton_mode()){
    /* So if the side button is being pressed, we increment the latch
       and move to the next application.  Some applications, such as
       the calculator, might hijack the call, so if we are latched for
       too many polling cycles, we forcibly revert to the clock
       application.
    */

    //Politely move to the next app if requested.
    if(!(latch++)){
      //lcd_zero();
      app_next();
    }
    
    //Force a shift to the home if held for 4 seconds (16 polls)
    if(latch>16)
      app_forcehome();
    
    /* Similarly, we'll reboot if the SET/PRGM button has been held
       for 10 seconds (40 polls).  We'll draw a countdown if getting
       close, so there's no ambiguity as to whether the chip reset.
       
       The other features of this button are handled within each
       application's draw function.
    */
    if(latch>40)
      PMMCTL0 = PMMPW | PMMSWPOR;
    
  }else{
    latch=0;
  }

  /* The applet is drawn four times per second, except for the clock,
     which is only drawn once a second.  We handle double-buffering,
     so that incomplete drawings won't be shown to the user, but
     everything else is the app's responsibility. */
  if(applet->draw!=clock_draw || (oldsec!=RTCSEC)){
    oldsec=RTCSEC;
    
    lcd_predraw();
    app_draw(0); //Unforced, because it's a regular timer.
    lcd_postdraw();
  }
}

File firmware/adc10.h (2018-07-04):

/* ADC10 definitions for the CC430F6147, so that we can target both
   the 6137 and the 6147 with a single firmware image.  periph.x was
   also modified.`
 */

/************************************************************
* ADC10_A
************************************************************/
#define __MSP430_HAS_ADC10_A__        /* Definition to show that Module is available */
#define __MSP430_BASEADDRESS_ADC10_A__ 0x0740

#define ADC10CTL0_            0x0740    /* ADC10 Control 0 */
sfrb(ADC10CTL0_L , ADC10CTL0_);
sfrb(ADC10CTL0_H , ADC10CTL0_+1);
sfrw(ADC10CTL0, ADC10CTL0_);
#define ADC10CTL1_            0x0742    /* ADC10 Control 1 */
sfrb(ADC10CTL1_L , ADC10CTL1_);
sfrb(ADC10CTL1_H , ADC10CTL1_+1);
sfrw(ADC10CTL1, ADC10CTL1_);
#define ADC10CTL2_            0x0744    /* ADC10 Control 2 */
sfrb(ADC10CTL2_L , ADC10CTL2_);
sfrb(ADC10CTL2_H , ADC10CTL2_+1);
sfrw(ADC10CTL2, ADC10CTL2_);
#define ADC10LO_              0x0746    /* ADC10 Window Comparator High Threshold */
sfrb(ADC10LO_L , ADC10LO_);
sfrb(ADC10LO_H , ADC10LO_+1);
sfrw(ADC10LO, ADC10LO_);
#define ADC10HI_              0x0748    /* ADC10 Window Comparator High Threshold */
sfrb(ADC10HI_L , ADC10HI_);
sfrb(ADC10HI_H , ADC10HI_+1);
sfrw(ADC10HI, ADC10HI_);
#define ADC10MCTL0_           0x074A    /* ADC10 Memory Control 0 */
sfrb(ADC10MCTL0_L , ADC10MCTL0_);
sfrb(ADC10MCTL0_H , ADC10MCTL0_+1);
sfrw(ADC10MCTL0, ADC10MCTL0_);
#define ADC10MEM0_            0x0752    /* ADC10 Conversion Memory 0 */
sfrb(ADC10MEM0_L , ADC10MEM0_);
sfrb(ADC10MEM0_H , ADC10MEM0_+1);
sfrw(ADC10MEM0, ADC10MEM0_);
#define ADC10IE_              0x075A    /* ADC10 Interrupt Enable */
sfrb(ADC10IE_L , ADC10IE_);
sfrb(ADC10IE_H , ADC10IE_+1);
sfrw(ADC10IE, ADC10IE_);
#define ADC10IFG_             0x075C    /* ADC10 Interrupt Flag */
sfrb(ADC10IFG_L , ADC10IFG_);
sfrb(ADC10IFG_H , ADC10IFG_+1);
sfrw(ADC10IFG, ADC10IFG_);
#define ADC10IV_              0x075E    /* ADC10 Interrupt Vector Word */
sfrb(ADC10IV_L , ADC10IV_);
sfrb(ADC10IV_H , ADC10IV_+1);
sfrw(ADC10IV, ADC10IV_);

/* ADC10CTL0 Control Bits */
#define ADC10SC             (0x0001)  /* ADC10 Start Conversion */
#define ADC10ENC            (0x0002)  /* ADC10 Enable Conversion */
#define ADC10ON             (0x0010)  /* ADC10 On/enable */
#define ADC10MSC            (0x0080)  /* ADC10 Multiple SampleConversion */
#define ADC10SHT0           (0x0100)  /* ADC10 Sample Hold Select Bit: 0 */
#define ADC10SHT1           (0x0200)  /* ADC10 Sample Hold Select Bit: 1 */
#define ADC10SHT2           (0x0400)  /* ADC10 Sample Hold Select Bit: 2 */
#define ADC10SHT3           (0x0800)  /* ADC10 Sample Hold Select Bit: 3 */

/* ADC10CTL0 Control Bits */
#define ADC10SC_L           (0x0001)  /* ADC10 Start Conversion */
#define ADC10ENC_L          (0x0002)  /* ADC10 Enable Conversion */
#define ADC10ON_L           (0x0010)  /* ADC10 On/enable */
#define ADC10MSC_L          (0x0080)  /* ADC10 Multiple SampleConversion */

/* ADC10CTL0 Control Bits */
#define ADC10SHT0_H         (0x0001)  /* ADC10 Sample Hold Select Bit: 0 */
#define ADC10SHT1_H         (0x0002)  /* ADC10 Sample Hold Select Bit: 1 */
#define ADC10SHT2_H         (0x0004)  /* ADC10 Sample Hold Select Bit: 2 */
#define ADC10SHT3_H         (0x0008)  /* ADC10 Sample Hold Select Bit: 3 */

#define ADC10SHT_0          (0x0000) /* ADC10 Sample Hold Select 0 */
#define ADC10SHT_1          (0x0100) /* ADC10 Sample Hold Select 1 */
#define ADC10SHT_2          (0x0200) /* ADC10 Sample Hold Select 2 */
#define ADC10SHT_3          (0x0300) /* ADC10 Sample Hold Select 3 */
#define ADC10SHT_4          (0x0400) /* ADC10 Sample Hold Select 4 */
#define ADC10SHT_5          (0x0500) /* ADC10 Sample Hold Select 5 */
#define ADC10SHT_6          (0x0600) /* ADC10 Sample Hold Select 6 */
#define ADC10SHT_7          (0x0700) /* ADC10 Sample Hold Select 7 */
#define ADC10SHT_8          (0x0800) /* ADC10 Sample Hold Select 8 */
#define ADC10SHT_9          (0x0900) /* ADC10 Sample Hold Select 9 */
#define ADC10SHT_10         (0x0A00) /* ADC10 Sample Hold Select 10 */
#define ADC10SHT_11         (0x0B00) /* ADC10 Sample Hold Select 11 */
#define ADC10SHT_12         (0x0C00) /* ADC10 Sample Hold Select 12 */
#define ADC10SHT_13         (0x0D00) /* ADC10 Sample Hold Select 13 */
#define ADC10SHT_14         (0x0E00) /* ADC10 Sample Hold Select 14 */
#define ADC10SHT_15         (0x0F00) /* ADC10 Sample Hold Select 15 */

/* ADC10CTL1 Control Bits */
#define ADC10BUSY           (0x0001)    /* ADC10 Busy */
#define ADC10CONSEQ0        (0x0002)    /* ADC10 Conversion Sequence Select 0 */
#define ADC10CONSEQ1        (0x0004)    /* ADC10 Conversion Sequence Select 1 */
#define ADC10SSEL0          (0x0008)    /* ADC10 Clock Source Select 0 */
#define ADC10SSEL1          (0x0010)    /* ADC10 Clock Source Select 1 */
#define ADC10DIV0           (0x0020)    /* ADC10 Clock Divider Select 0 */
#define ADC10DIV1           (0x0040)    /* ADC10 Clock Divider Select 1 */
#define ADC10DIV2           (0x0080)    /* ADC10 Clock Divider Select 2 */
#define ADC10ISSH           (0x0100)    /* ADC10 Invert Sample Hold Signal */
#define ADC10SHP            (0x0200)    /* ADC10 Sample/Hold Pulse Mode */
#define ADC10SHS0           (0x0400)    /* ADC10 Sample/Hold Source 0 */
#define ADC10SHS1           (0x0800)    /* ADC10 Sample/Hold Source 1 */

/* ADC10CTL1 Control Bits */
#define ADC10BUSY_L         (0x0001)    /* ADC10 Busy */
#define ADC10CONSEQ0_L      (0x0002)    /* ADC10 Conversion Sequence Select 0 */
#define ADC10CONSEQ1_L      (0x0004)    /* ADC10 Conversion Sequence Select 1 */
#define ADC10SSEL0_L        (0x0008)    /* ADC10 Clock Source Select 0 */
#define ADC10SSEL1_L        (0x0010)    /* ADC10 Clock Source Select 1 */
#define ADC10DIV0_L         (0x0020)    /* ADC10 Clock Divider Select 0 */
#define ADC10DIV1_L         (0x0040)    /* ADC10 Clock Divider Select 1 */
#define ADC10DIV2_L         (0x0080)    /* ADC10 Clock Divider Select 2 */

/* ADC10CTL1 Control Bits */
#define ADC10ISSH_H         (0x0001)    /* ADC10 Invert Sample Hold Signal */
#define ADC10SHP_H          (0x0002)    /* ADC10 Sample/Hold Pulse Mode */
#define ADC10SHS0_H         (0x0004)    /* ADC10 Sample/Hold Source 0 */
#define ADC10SHS1_H         (0x0008)    /* ADC10 Sample/Hold Source 1 */

#define ADC10CONSEQ_0        (0x0000)      /* ADC10 Conversion Sequence Select: 0 */
#define ADC10CONSEQ_1        (0x0002)      /* ADC10 Conversion Sequence Select: 1 */
#define ADC10CONSEQ_2        (0x0004)      /* ADC10 Conversion Sequence Select: 2 */
#define ADC10CONSEQ_3        (0x0006)      /* ADC10 Conversion Sequence Select: 3 */

#define ADC10SSEL_0          (0x0000)      /* ADC10 Clock Source Select: 0 */
#define ADC10SSEL_1          (0x0008)      /* ADC10 Clock Source Select: 1 */
#define ADC10SSEL_2          (0x0010)      /* ADC10 Clock Source Select: 2 */
#define ADC10SSEL_3          (0x0018)      /* ADC10 Clock Source Select: 3 */
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

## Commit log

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2017-04-14 Initial project file and LCD schematic library. #1
    [goodwatch10.kicad_pcb, goodwatch10.sch]
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2017-04-15 Working hard in the CAD coal mines. #3
    [goodwatch10.sch]
2017-04-15 Lots of CAD work. #4 #3
    [goodwatch10.kicad_pcb, goodwatch10.sch]
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2017-04-15 Lots of CAD layout, fixing sizes and routing. #4 #3 #2
    [goodwatch10.kicad_pcb, goodwatch10.sch]
2017-04-15 More layout and fixes. #3 #1 #4
    [goodwatch10.kicad_pcb, goodwatch10.sch]
2017-08-31 Beginning to route LCD and keypad.
    [goodwatch10.kicad_pcb, goodwatch10.sch]
2017-08-31 Almost everythingin GW10 layout. Still missing SBW connector.
    [goodwatch10.kicad_pcb, goodwatch10.sch]
2017-09-01 Initial layout is complete! I'll clean up the BOM and order a round of boards.
    [goodwatch10.kicad_pcb, goodwatch10.sch]
2017-09-02 Converted C4 to 0402, as necessary for its value.
    [goodwatch10.kicad_pcb, goodwatch10.sch]
2017-09-02 Switched C1 to 0603.
    [goodwatch10.kicad_pcb, goodwatch10.sch]
2017-09-02 Final BOM and part layouts.
    [goodwatch10.kicad_pcb, goodwatch10.sch]
2017-09-03 Crystal now renders in 3D. Moved the label locations for easier assembly.
    [goodwatch10.kicad_pcb]
2017-09-03 GoodWatch10 Gerbers. These won't be touched after I send the design for fabrication.
    [goodwatch10-B.Cu.gbr, goodwatch10-B.Mask.gbr, goodwatch10-B.SilkS.gbr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]
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2017-09-03 Second round of gerbers, now with proper drilling.
    [goodwatch10-B.Cu.gbl, goodwatch10-B.Mask.gbs, goodwatch10-B.SilkS.gbo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]
2017-09-03 Final gerbers, I think.
    [goodwatch10-B.Cu.gbl, goodwatch10-B.Mask.gbs, goodwatch10-B.SilkS.gbo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]
2017-09-03 Fill layers, proper gerber configuration.
    [goodwatch10.kicad_pcb]
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2017-09-06 Updated gerbers to fix clearence issues in #6.
    [goodwatch10-B.Cu.gbl, goodwatch10-B.Mask.gbs, goodwatch10-B.SilkS.gbo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]
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2017-09-24 Fixed all compiler warnings.
    [main.c]
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2017-09-25 Fixes clock sources and power management. RTC is now sourced from XT1. Close #14.
    [main.c]
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2017-10-03 More work on the GW20 layout. This will be a tight squeeze. #7 #19
    [goodwatch20.kicad_pcb, goodwatch20.sch]
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2017-10-03 Loading capacitors for XT2 in the GW20. #7
    [goodwatch20.kicad_pcb, goodwatch20.sch]
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2017-10-14 More of the antenna chain. No filters yet. #7
    [goodwatch20.kicad_pcb, goodwatch20.sch]
2017-10-15 Antenna layout could be cleaner, but I think this will work. #7 #19
    [goodwatch20.kicad_pcb, goodwatch20.sch]
2017-10-22 POST now tests for an oscillator fault. Close #35.
    [main.c]
2017-10-31 Removed ground planes from beneath antenna. Needs more groundplane vias, most likely. #7 #19
    [goodwatch20.kicad_pcb]
2017-10-31 Bit more layout toward #19, trying for sturdier ground planes.
    [goodwatch20.kicad_pcb]
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2017-10-31 Routing LCD common pins along the edge to retain lower ground plane. All DRC passes in layout. #19
    [goodwatch20.kicad_pcb]
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2017-11-01 Moved programming pads and the low frequency crystal for better placement. #19
    [goodwatch20.kicad_pcb]
2017-11-01 Adds a ground pad for programming without soldering. #13 #19
    [goodwatch20.kicad_pcb, goodwatch20.sch]
2017-11-01 Added a pad to the board for the buzzer. Not yet wired to GPIO. #19
    [goodwatch20.kicad_pcb]
2017-11-01 Routing for the buzzer pad, not yet wired. #19
    [goodwatch20.kicad_pcb]
2017-11-02 Buzzer now runs to P2.7. Placed some silk-screen labels. #19
    [goodwatch20.kicad_pcb, goodwatch20.sch]
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2017-11-02 BOM and gerbers for the GW20 layout. Close #19.
    [goodwatch20-B.Cu.gbl, goodwatch20-B.Mask.gbs, goodwatch20-B.SilkS.gbo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]
2017-11-13 Holding SET/PRGM for ten seconds will now trigger a Power-On-Reset. Close #38.
    [main.c]
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2017-11-16 Successfully identifies missing radio on GoodWatch10. #44
    [main.c]
2017-11-18 Fixes core voltage scaling.
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2017-11-19 Cleanup of the RF1A library. No longer displays useless errors. #44
    [main.c]
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2017-11-30 Fixes bug where app_init() was not called for the first application.
    [main.c]
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2017-12-05 Update BOM for mouser.fr part
    Add replacement part number used in mouser.fr for C1
2017-12-05 goodwatch20 BOM typo fix
    1276-6528-1-ND is a 0603 Package
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2017-12-10 Failed attempt at #56. UART monitor can now transmit packets. #55 Cleanups to the beacon. #53
    [monitor.c, uart.c]
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2018-01-15 Rechargable battery datasheet. Capacity is too low, I think.
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2018-02-06 Beginning the GoodWatch21 gerbers. #74 Includes Piotr's adjustment of the solder stop to 0.05. Close #71. Close #70.
    [goodwatch21.kicad_pcb, goodwatch21.sch]
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2018-02-06 working on buzzer driver
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2018-02-07 progress, but no cigar yet on the buzzer
    [main.c]
2018-02-07 keypad.c now avoids the buzzer pin. #77
2018-02-08 Basics of a buzzer. Needs some hardware modifications. #77
    [main.c]
2018-02-10 buzzer is working on my watch
    [main.c]
2018-02-10 use Travis' buzz driver instead of mine, re-add alarm app to list
    [main.c]
2018-02-12 Small changes to LCD font
    Distinguishing U, V and W was a pain. Switched W to be the same
    as inverted M and distinguished U and V by case.
    Also, we have enough pixels for nice uppercase Y and lowercase t.
    K and X are only pair that seem a bit confusing, but . is ok I guess.
2018-02-13 Fixes bug where a forced exit from the RPN applet would leave the device in high-speed mode.
2018-03-31 GoodWatch21 gerbers and schematics have been finalized. #74
    [goodwatch21-B.Cu.gbl, goodwatch21-B.Mask.gbs, goodwatch21-B.SilkS.gbo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]
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2018-07-23 Schematics and placement for GoodWatch22, #95. Not yet finalized.
    [goodwatch22.kicad_pcb, goodwatch22.sch]
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2018-07-23 No longer prints the REF status during POST.
    [main.c]
2018-07-24 Calibration no longer users getchar(). #97
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2018-07-30 Minor repositioning of silkscreen text and ground connections. #95
    [goodwatch22.kicad_pcb]
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2018-08-01 Initial draft of GW30 ported to Kicad 5. #99
    [goodwatch30.kicad_pcb, goodwatch30.sch]
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2018-08-02 Fixes Kicad footprint library path in Kicad 5. #100
2018-08-02 Footprints for the new balun and filters. #40 #100
    [goodwatch30.sch]
2018-08-02 Fixed the LP15 low pass filter layout. #40 #100
    [goodwatch30.sch]
2018-08-02 GW30 is now looking good, with the new balue. #100 #40
    [goodwatch30.kicad_pcb, goodwatch30.sch]
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2018-08-03 Fixes bug where hex app would forget to draw its first frame.
2018-08-17 Updated all generic footprints to KiCAD V5 versions.
    This includes roundrect pads for generic pads and correct references to
    the 3d models.
    [goodwatch30.kicad_pcb, goodwatch30.sch]
2018-08-17 A bunch of nitpicky routing cleanup.
    * removed some sharp trace corners
    * Replaced Y joints with T joints (wider angles -> smaller chance of
    acid traps)
    * Using a second GND fill polygon with smaller trace/space for the tiny
    parts on the back of the board.
    * Using fill polygons to connect RFVCC instead of a trace mesh.
    * Removed some remaining GND traces that are not needed any more in
    KiCAD V5
    * Cleaned up connections to footprints that changed shape slightly in
    the V5 update.
    [goodwatch30.kicad_pcb]
2018-08-17 Entered sheet data into she sheet dialog instead of free floating text.
    [goodwatch30.kicad_pcb, goodwatch30.sch]
2018-08-17 Some minor improvements of the custom footprints.
    * Added Courtyards to all the custom footprints. (0.25mm border around a
    part to make sure a P&P machine can populate the parts without knocking
    off something next to the part.)
    * Relocated parts to have their x,y 0 at the center of the parts.
    Otherwise the centroid data for the Pick&Place machine are offset and
    cause trouble. (You center through hole parts on pins and SMD parts at
    it's convex hull centroid)
    * Replaced square pads with roundrect where it makes sense. Roundrect
    has better solder paste stencil release characteristics as well as
    better flow characteristics in manufacturing.
    [goodwatch30.kicad_pcb, goodwatch30.sch]
2018-08-17 Seme additional cosmetic routing fixes.
    [goodwatch30.kicad_pcb]
2018-08-18 Minor cleanup, shabbat mode fixes.
    [main.c, sidebutton.c]
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2018-09-03 Added rounded corners to the PCB.
    The original board has 2.5mm radius rounded corners. Now we do too! :)
    [goodwatch30.kicad_pcb, goodwatch30.sch]
2018-09-03 Changed all via to 0.5/0.3 to gain some more routing room.
    [goodwatch30.kicad_pcb]
2018-09-03 Decreased default trace width to 0.15mm (~6mil).
    This is a fairly common trace space width and also SI units FTW. ;)
    [goodwatch30.kicad_pcb]
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2018-09-03 Added outline of the top side enclosure pocket to the board footprint.
    Based on measurements of the plastic moulding on the IC side of the
    board. The outline of the enclosure recess is on ECO1 layer.
    [goodwatch30.kicad_pcb, goodwatch30.sch]
2018-09-03 Replaced all 0201 parts except the 0.1u for 0402.
    I did not change the 0.1u yet as we have 3 of them on the back side of
    the board. They are decoupling caps so they should be as close as
    possible to the power pins. So moving them to a spot that can accept a
    higher part might be difficult. Although we could use 0402 that are
    <0.33mm thick too. This would fit our budget and make assembly easier.
    Thus I will make the change in a separate commit.
    [goodwatch30.kicad_pcb, goodwatch30.sch]
2018-09-03 Converted the 0201 0.1u caps to 0402.
    As some of them are on the bottom side of the board we have to use
    <0.33mm high components. The bom reflects that in the key and part note.
    [goodwatch30.kicad_pcb, goodwatch30.sch]
2018-09-03 Updated BOM.txt and synchronized to the schematic.
    Added datasheet links to all non trivial parts in the schematic.
    [goodwatch30.sch]
2018-09-03 Changed the 26mhz oscillator load capacitors to 12pF.
    [goodwatch30.kicad_pcb, goodwatch30.sch]
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2018-09-23 Fixes the broken UART by intializing it after the sidebuttons.
    [main.c]
2018-09-23 Uart no longer displayed on LCD at startup.
    [main.c]
2018-09-23 Codeplug frequency no longer set by monitor on every configuration.
    [monitor.c]
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2018-09-26 Fixes SET button and adjusts Makefile to flash codeplug with firmware over SBW.
    [uart.c]
2018-09-28 Fixes power consumption problem in devices without radios. Close #108.
2018-10-07 buildtime.h now contains the compilation time, fixing broken start times in JTAG-programmed boards. Close #106.
2018-10-09 Saves ~250µA during button presses by fixing a bug that caused the GPIO interrupt to repeatedly trigger as long as the button was down.
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2018-11-03 Fix to the sidebutton reboot from @BitBangingBytes. Close #110.
    [main.c]
2018-11-11 Codeplug is now stored in regular flash, rather than info flash. Fixes tuner in SBW-flashed devices.
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2019-02-23 Fixes a bug where long interrupt handlers might leave the keypad interrupt handler stuck.
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2019-05-17 Fixes printsizes.py to show .rodata usage.
2019-05-19 GCC7 is linking and fits within firmware. This required a printf() replacement. #119
    [main.c]
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2019-09-01 Border is now corrected for 3D rendering. #121
    [goodwatch31.kicad_pcb]
2019-09-08 Added 2D and 3D models of the frame
    [Battery_frame_3D.fcstd, LCD_frame_3D.fcstd]
2019-09-08 Created missing 3D models
    [Balun.fcstd, Crystal.fcstd, LPF.fcstd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]
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2020-01-23 Hebrew Calender, GCC8 and Fall-Through Buttons (#141)
    * Library support for the hebrew calendar, with test cases. Not interface yet. #140
    * Cleanup for 16-bit cleanliness. Still not working in the watch. #140
    * Hebrew calendar app begins to work on the watch. #140
    * Finishes the Hebrew calendar and fall-through button support. GCC8 is now default. #140 #139 #119
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2020-12-26 Most of the layout, but still needs some caps. #147
    [PT-1203-3.stp, goodpocketwatch31.kicad_pcb]
2020-12-26 Bit more drafting, almost done with the pocket watch. #147
    [BE-AAAA-PC.stp, goodpocketwatch31.kicad_pcb, goodpocketwatch31.sch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]
2020-12-27 Layou of GPW31 is complete except for the SMA connector. #147
    [goodpocketwatch31.kicad_pcb, keypad.sch]
2020-12-27 Adds an edge-mount SMA connector, handy for RF accessories. #147
    [goodpocketwatch31.kicad_pcb, goodpocketwatch31.sch]
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2021-03-03 Corrected model of U3 to indicate pin 1 properly. #121
    [goodwatch31.kicad_pcb]
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
